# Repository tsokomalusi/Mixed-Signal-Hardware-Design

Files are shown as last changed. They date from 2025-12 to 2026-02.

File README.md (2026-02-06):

# Mixed-Signal-Hardware-Design

## 📌 Project Summary
This repository contains a mixed-signal hardware design project covering system-level design, schematic capture, analog simulation, and PCB layout.  
The project demonstrates best practices in analog/digital partitioning, component selection, simulation-driven design, and manufacturable PCB layout.

------------------------------------------------------------------------------------------------------------------------------------------------------------------------------------------
## 🧰 Tools Used
- **KiCad** – Schematic capture and PCB design  
- **LTSpice** – Analog circuit simulation  
- **STM32CubeIDE** – MCU pinout planning  
- **draw.io** – System block diagram
- **git and github** - version control system
-----------------------------------------------------------------------------------------------------------------------------------------------------------------------------------------
## 🧱 System Block Diagram

block_diagram

Refined version
  
block_diagram_refined

-----------------------------------------------------------------------------------------------------------------------------------------------------------------------------------------
## 🧩 Pinout Planning

mixed-signal-pinout_planning
-----------------------------------------------------------------------------------------------------------------------------------------------------------------------------------------
## 📐 Schematic Design

Root Sheet
root

Power circuitry
power

MCU circuitry
mcu

ADC circuirty
adc

DAC circuitry
dac

Key design considerations:
- Proper decoupling and grounding
- Separation of analog and digital domains
- Power integrity and signal integrity

------------------------------------------------------------------------------------------------------------------------------------------------------------------------------------------
## 🧩 PCB Layout

### PCB STACKUP 
- TOP LAYER :     SIG/POWER
- IN1 LAYER:      GND
- IN2 LAYER:      GND
- BOTTOM LAYER:   SIG/POWER

###  PCB All Layers
PCB_LAYOUT

### Top Layer
PCB_TOP

### Bottom Layer
PCB_BOTTOM

### 3D View
mixed_signal_hw_pcb_3D

PCB design highlights:
- Footprint creation
- Controlled impedance traces
- Avoiding: crosstalk, coupling, ground loops, inductance and radiation
- Via stitching, power puddles, keeping proper spacing between analog and digital circuits

-------------------------------------------------------------------------------------------------------------------------------------------------------------------------------------------
## 🔬 LTSpice Simulation

### AC Analysis Schematic
ac_analysis

### AC Analysis Response
ac_analysis_response

### DC Operating Point Analysis
dc_operating_point_analysis

DC_Operating_Point_Analysis

------------------------------------------------------------------------------------------------------------------------------------------------------------------------------------------
## 📜 License
This project is released for educational and portfolio purposes.

------------------------------------------------------------------------------------------------------------------------------------------------------------------------------------------
## 🙏 Acknowledgements

This project was developed as part of hands-on learning inspired by the course:

**“Mixed-Signal Hardware Design with KiCad”**  
Instructor: **Philip Salmony**  
Platform: **FEDEVEL Academy**  
Website: https://www.fedevel.com

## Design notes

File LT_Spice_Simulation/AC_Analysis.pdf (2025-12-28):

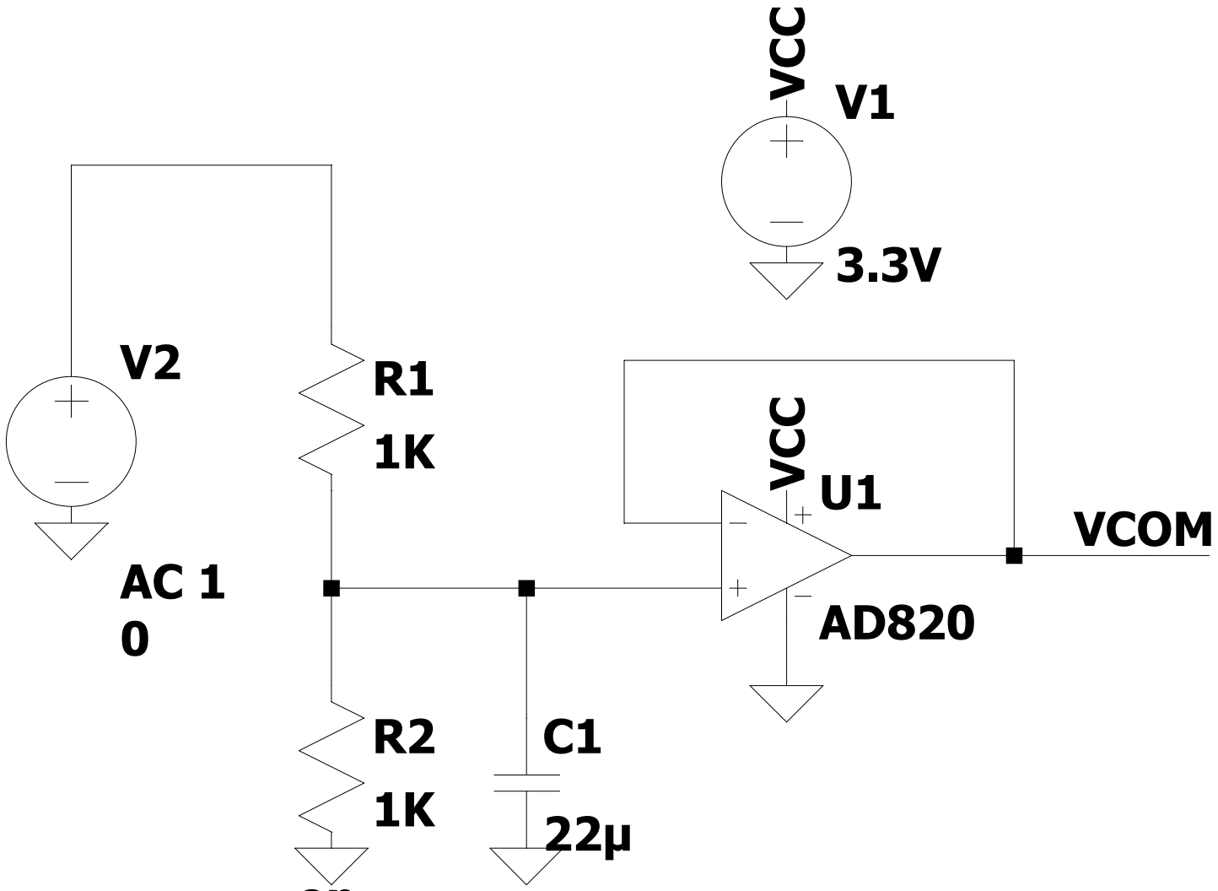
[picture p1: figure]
VCC VCC; VCOM

# .ac dec 100 1 25000

.op

--- C:\Users\Asus\OneDrive\Documents\LTspice\Draft1.asc ---

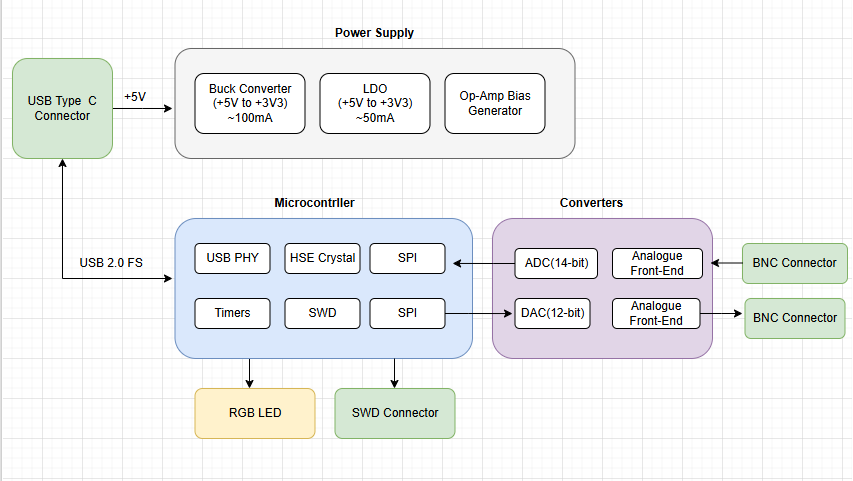
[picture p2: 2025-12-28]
Images/block_diagram_refined.png

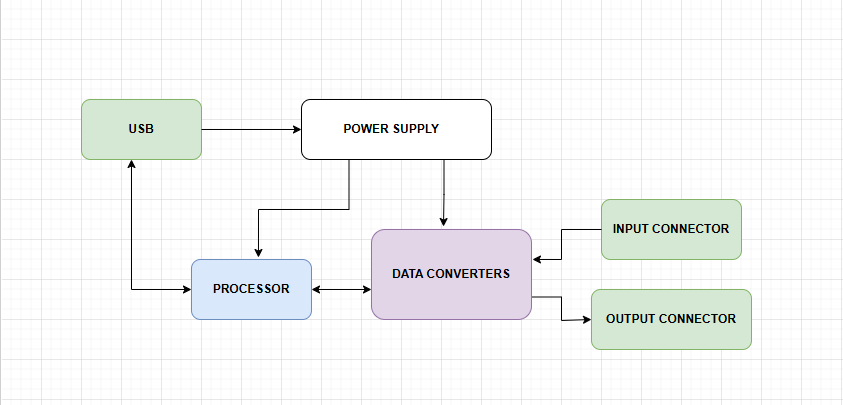
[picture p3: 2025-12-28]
Images/block_diagram.png

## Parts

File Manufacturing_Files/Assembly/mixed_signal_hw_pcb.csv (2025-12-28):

Reference | Qty | Value | Exclude from BOM | Exclude from Board | Footprint | Datasheet | Manufacturer | Manufacturer Part Number
Y200 | 1 | 16MHz |  |  | Crystal:Crystal_SMD_3225-4Pin_3.2x2.5mm | ~ | Epson | FA-238 16.000 MHz
U401 | 1 | MCP6001-OT |  |  | Package_TO_SOT_SMD:SOT-23-5 | https://ww1.microchip.com/downloads/en/DeviceDoc/MCP6001-1R-1U-2-4-1-MHz-Low-Power-Op-Amp-DS20001733L.pdf | Microchip Technology | MCP6001T‑I/OT
U400 | 1 | DAC7563SDGSR |  |  | DAC7563SDGSR:SOIC-10 |  | Texas Instruments | DAC7563SDGSR
U305 | 1 | MCP6001-OT |  |  | Package_TO_SOT_SMD:SOT-23-5 | https://ww1.microchip.com/downloads/en/DeviceDoc/MCP6001-1R-1U-2-4-1-MHz-Low-Power-Op-Amp-DS20001733L.pdf | Microchip Technology | MCP6001-OT
U303 | 1 | ADC141S626CIMM_NOPB |  |  | DAC7563SDGSR:SOIC-10 |  | Texas Instruments | ADC141S626CIMM
U302 | 1 | REF3033AIDBZ |  |  | Package_TO_SOT_SMD:SOT-23 | http://www.ti.com/lit/ds/symlink/ref3033.pdf | Texas Instruments | REF3033AIDBZ
U301 | 1 | MCP6001-OT |  |  | Package_TO_SOT_SMD:SOT-23-5 | https://ww1.microchip.com/downloads/en/DeviceDoc/MCP6001-1R-1U-2-4-1-MHz-Low-Power-Op-Amp-DS20001733L.pdf | Microchip Technology | MCP6001-OT
U300 | 1 | MCP6001-OT |  |  | Package_TO_SOT_SMD:SOT-23-5 | https://ww1.microchip.com/downloads/en/DeviceDoc/MCP6001-1R-1U-2-4-1-MHz-Low-Power-Op-Amp-DS20001733L.pdf | Microchip Technology | MCP6001-OT
U201 | 1 | USBLC6-2SC6 |  |  | Package_TO_SOT_SMD:SOT-23-6 | https://www.st.com/resource/en/datasheet/usblc6-2.pdf | ON Semiconductor | USBLC6-2SC6
U200 | 1 | STM32F103RCT6 |  |  | Package_QFP:LQFP-64_10x10mm_P0.5mm | https://www.st.com/resource/en/datasheet/stm32f103rc.pdf | STMicroelectronics | STM32F103RCT6
U101 | 1 | TLV62569DBV |  |  | Package_TO_SOT_SMD:SOT-23-5 | http://www.ti.com/lit/ds/symlink/tlv62568.pdf | Texas Instruments | TLV62569DBV
U100 | 1 | HT7533-1 |  |  | Package_TO_SOT_SMD:SOT-89-3 | https://www.holtek.com/documents/10179/116711/HT75xx-1v250.pdf | Holtek Semiconductor | HT7533-1
R405 | 1 | 49R9 |  |  | Resistor_SMD:R_0603_1608Metric | ~ | YAGEO | RC0603FR-0749R9L
R404 | 1 | 12K |  |  | Resistor_SMD:R_0603_1608Metric | ~ | YAGEO | RC0603FR-0712KL
R403 | 1 | 22K |  |  | Resistor_SMD:R_0603_1608Metric | ~ | YAGEO | RC0603FR-0722KL
R402 | 1 | 6K8 |  |  | Resistor_SMD:R_0603_1608Metric | ~ | YAGEO | RC0603FR-076K8L
R401 | 1 | 10K |  |  | Resistor_SMD:R_0603_1608Metric | ~ | YAGEO | RC0603FR-0710KL
R400 | 1 | 0R |  |  | Resistor_SMD:R_0603_1608Metric | ~ | YAGEO | RC0603JR-070RL
R309 | 1 | 0R |  |  | Resistor_SMD:R_0603_1608Metric | ~ | Yageo | RC0603JR-070RL
R308 | 1 | 49R9 |  |  | Resistor_SMD:R_0603_1608Metric | ~ | Yageo | RC0603FR-0749R9L
R307 | 1 | 1K |  |  | Resistor_SMD:R_0603_1608Metric | ~ | Yageo | RC0603FR-071KL
R306 | 1 | 1K |  |  | Resistor_SMD:R_0603_1608Metric | ~ | Yageo | RC0603FR-071KL
R305 | 1 | 12K |  |  | Resistor_SMD:R_0603_1608Metric | ~ | Yageo | RC0603FR-0712KL
R304 | 1 | 22K |  |  | Resistor_SMD:R_0603_1608Metric | ~ | Yageo | RC0603FR-0722KL
R303 | 1 | 6K8 |  |  | Resistor_SMD:R_0603_1608Metric | ~ | Yageo | RC0603FR-076K8L
R302 | 1 | 2M2 |  |  | Resistor_SMD:R_0805_2012Metric | ~ | Yageo | RC0805FR-072M2L
R301 | 1 | 2M2 |  |  | Resistor_SMD:R_0805_2012Metric | ~ | Yageo | RC0805FR-072M2L
R300 | 1 | 1K |  |  | Resistor_SMD:R_0603_1608Metric | ~ | Yageo | RC0603FR-071KL
R213 | 1 | 5K1 |  |  | Resistor_SMD:R_0603_1608Metric | ~ | Yageo | RC0603FR-075K1L
R212 | 1 | 5K1 |  |  | Resistor_SMD:R_0603_1608Metric | ~ | Yageo | RC0603FR-075K1L
R211 | 1 | 49R9 |  |  | Resistor_SMD:R_0603_1608Metric | ~ | Yageo | RC0603FR-0749R9L
R210 | 1 | 49R9 |  |  | Resistor_SMD:R_0603_1608Metric | ~ | Yageo | RC0603FR-0749R9L
R209 | 1 | 49R9 |  |  | Resistor_SMD:R_0603_1608Metric | ~ | Yageo | RC0603FR-0749R9L
R208 | 1 | 49R9 |  |  | Resistor_SMD:R_0603_1608Metric | ~ | Yageo | RC0603FR-0749R9L
R207 | 1 | 1K |  |  | Resistor_SMD:R_0603_1608Metric | ~ | Yageo | RC0603FR-071KL
R206 | 1 | 1K |  |  | Resistor_SMD:R_0603_1608Metric | ~ | Yageo | RC0603FR-071KL
R205 | 1 | 1K |  |  | Resistor_SMD:R_0603_1608Metric | ~ | Yageo | RC0603FR-071KL
R204 | 1 | 10K |  |  | Resistor_SMD:R_0603_1608Metric | ~ | Yageo | RC0603FR-0710KL
R203 | 1 | 1K5 |  |  | Resistor_SMD:R_0603_1608Metric | ~ | Yageo | RC0603FR-071K5L
R202 | 1 | 0R |  |  | Resistor_SMD:R_0603_1608Metric | ~ | Yageo | RC0603JR-070RL
R201 | 1 | 10K |  |  | Resistor_SMD:R_0603_1608Metric | ~ | Yageo | RC0603FR-0710KL
R200 | 1 | 10K |  |  | Resistor_SMD:R_0603_1608Metric | ~ | Yageo | RC0603FR-0710KL
R105 | 1 | 1K |  |  | Resistor_SMD:R_0603_1608Metric | ~ | YAGEO | RC0603FR-071KL
R104 | 1 | 1K |  |  | Resistor_SMD:R_0603_1608Metric | ~ | YAGEO | RC0603FR-071KL
R103 | 1 | 1K |  |  | Resistor_SMD:R_0603_1608Metric | ~ | YAGEO | RC0603FR-071KL
R102 | 1 | 22K |  |  | Resistor_SMD:R_0603_1608Metric | ~ | YAGEO | RC0603FR-0722KL
R101 | 1 | 100K |  |  | Resistor_SMD:R_0603_1608Metric | ~ | YAGEO | RC0603FR-07100KL
R100 | 1 | 10R |  |  | Resistor_SMD:R_0603_1608Metric | ~ | YAGEO | RC0603FR-0710RL
L200 | 1 | 10n |  |  | Inductor_SMD:L_0603_1608Metric | ~ | Murata | LQW18AN10NJ00D
L101 | 1 | 68u |  |  | Inductor_SMD:L_Sunlord_MWSA0603S | ~ | Sunlord | MWSA0603S-680K
L100 | 1 | 10n |  |  | Inductor_SMD:L_0603_1608Metric | ~ | Sunlord | MWSA0603S-100J
J400 | 1 | DOSIN-801-0031 |  |  | Connector_DIN:BNC | ~ | dosinconn | DOSIN-801-003
J300 | 1 | DOSIN-801-0031 |  |  | Connector_DIN:BNC | ~ | dosinconn | DOSIN-801-003
J201 | 1 | 2X5X1.27mm |  |  | Connector_PinHeader_1.27mm:PinHeader_2x05_P1.27mm_Vertical_SMD | ~ | Samtec | FTSH-105-01-L-DV-K
J200 | 1 | USB_C_Receptacle_USB2.0_16P |  |  | Connector_USB:USB_C_Receptacle_HRO_TYPE-C-31-M-12 | https://www.usb.org/sites/default/files/documents/usb_type-c.zip | Korean Hroparts Elec | TYPE-C-31-M-12
H4 | 1 | MountingHole_Pad | Excluded from BOM |  | MountingHole:MountingHole_3.2mm_M3_Pad_Via | ~
H3 | 1 | MountingHole_Pad | Excluded from BOM |  | MountingHole:MountingHole_3.2mm_M3_Pad_Via | ~
H2 | 1 | MountingHole_Pad | Excluded from BOM |  | MountingHole:MountingHole_3.2mm_M3_Pad_Via | ~
H1 | 1 | MountingHole_Pad | Excluded from BOM |  | MountingHole:MountingHole_3.2mm_M3_Pad_Via | ~
FL200 | 1 | DLW21SN900SQ2L |  |  | Inductor_SMD:choke | https://productfinder.pulseelectronics.com/api/open/product-attachments/datasheet/ph9455.105nl | Murata Electronics | DLW21SN900SQ2L
D400 | 1 | PESD3V3L1BA.115 |  |  | Diode_SMD:D_SOD-323 | https://www.littelfuse.com/~/media/electronics/datasheets/tvs_diode_arrays/littelfuse_tvs_diode_array_sd_c_datasheet.pdf.pdf | Nexperia | PESD3V3L1BA,115
D300 | 1 | PESD3V3L1BA.115 |  |  | Diode_SMD:D_SOD-323 | https://www.littelfuse.com/~/media/electronics/datasheets/tvs_diode_arrays/littelfuse_tvs_diode_array_sd_c_datasheet.pdf.pdf | Nexperia | PESD3V3L1BA,115
D205 | 1 | SD05_SOD323 |  |  | Diode_SMD:D_SOD-323 | https://www.littelfuse.com/~/media/electronics/datasheets/tvs_diode_arrays/littelfuse_tvs_diode_array_sd_c_datasheet.pdf.pdf | Nexperia | PESD3V3L1BA,115
D204 | 1 | SD05_SOD323 |  |  | Diode_SMD:D_SOD-323 | https://www.littelfuse.com/~/media/electronics/datasheets/tvs_diode_arrays/littelfuse_tvs_diode_array_sd_c_datasheet.pdf.pdf | Nexperia | PESD3V3L1BA,115
D203 | 1 | SD05_SOD323 |  |  | Diode_SMD:D_SOD-323 | https://www.littelfuse.com/~/media/electronics/datasheets/tvs_diode_arrays/littelfuse_tvs_diode_array_sd_c_datasheet.pdf.pdf | Nexperia | PESD3V3L1BA,115
D202 | 1 | PESD3V3L1BA,115 |  |  | Diode_SMD:D_SOD-323 | https://www.littelfuse.com/~/media/electronics/datasheets/tvs_diode_arrays/littelfuse_tvs_diode_array_sd_c_datasheet.pdf.pdf | Nexperia | PESD3V3L1BA,115
D201 | 1 | PESD3V3L1BA,115 |  |  | Diode_SMD:D_SOD-323 | https://www.littelfuse.com/~/media/electronics/datasheets/tvs_diode_arrays/littelfuse_tvs_diode_array_sd_c_datasheet.pdf.pdf | Nexperia | PESD3V3L1BA,115
D200 | 1 | LED_ARGB |  |  | LED_SMD:LED_AAA3528LSEEZGKQBKS_KNB | ~ | Kingbright | AAA3528LSEEZGKQBKS
D100 | 1 | GREEN |  |  | Diode_SMD:D_0805_2012Metric | ~ | LITEON | LTST-C170FKT
C406 | 1 | 100n |  |  | Capacitor_SMD:C_0603_1608Metric | ~ | YAGEO | CC0603ZRY5V7BB104
C405 | 1 | 1n |  |  | Capacitor_SMD:C_0603_1608Metric | ~ | Vishay / Vitramon | VJ0603H102KEBAO34
C404 | 1 | 150p |  |  | Capacitor_SMD:C_0603_1608Metric | ~ | Vishay / Vitramon | VJ0603A151JXAAC
C403 | 1 | 1n |  |  | Capacitor_SMD:C_0603_1608Metric | ~ | Vishay / Vitramon | VJ0603H102KEBAO34
C402 | 1 | 1u |  |  | Capacitor_SMD:C_0805_2012Metric | ~ | KYOCERA AVX | 08055D105KAT2A
C401 | 1 | 100n |  |  | Capacitor_SMD:C_0603_1608Metric | ~ | YAGEO | CC0603ZRY5V7BB104
C400 | 1 | 10u |  |  | Capacitor_SMD:C_0805_2012Metric | ~ | KYOCERA AVX | 0805X7R106KT1AT
C315 | 1 | 10u |  |  | Capacitor_SMD:C_0805_2012Metric | ~ | KYOCERA AVX | 0805X7R106KT1AT
C314 | 1 | 100n |  |  | Capacitor_SMD:C_0603_1608Metric | ~ | YAGEO | CC0603ZRY5V7BB104
C313 | 1 | 100n |  |  | Capacitor_SMD:C_0603_1608Metric | ~ | YAGEO | CC0603ZRY5V7BB104
C312 | 1 | 10u |  |  | Capacitor_SMD:C_0805_2012Metric | ~ | KYOCERA AVX | 0805X7R106KT1AT
C311 | 1 | 100n |  |  | Capacitor_SMD:C_0603_1608Metric | ~ | YAGEO | CC0603ZRY5V7BB104
C310 | 1 | 10u |  |  | Capacitor_SMD:C_0805_2012Metric | ~ | KYOCERA AVX | 0805X7R106KT1AT
C309 | 1 | 10u |  | Excluded from board | Capacitor_SMD:C_0805_2012Metric | ~ | KYOCERA AVX | 0805X7R106KT1AT
C308 | 1 | 10u |  |  | Capacitor_SMD:C_0805_2012Metric | ~ | KYOCERA AVX | 0805X7R106KT1AT
C307 | 1 | 150p |  |  | Capacitor_SMD:C_0603_1608Metric | ~ | Vishay / Vitramon | VJ0603A151JXAAC
C306 | 1 | 100n |  |  | Capacitor_SMD:C_0603_1608Metric | ~ | YAGEO | CC0603ZRY5V7BB104
C305 | 1 | 150p |  |  | Capacitor_SMD:C_0603_1608Metric | ~ | Vishay / Vitramon | VJ0603A151JXAAC
C304 | 1 | 1n |  |  | Capacitor_SMD:C_0603_1608Metric | ~ | Vishay / Vitramon | VJ0603H102KEBAO34
C303 | 1 | 1n |  |  | Capacitor_SMD:C_0603_1608Metric | ~ | Vishay / Vitramon | VJ0603H102KEBAO34
C302 | 1 | 100n |  |  | Capacitor_SMD:C_0603_1608Metric | ~ | YAGEO | CC0603ZRY5V7BB104
C301 | 1 | 100n |  |  | Capacitor_SMD:C_0603_1608Metric | ~ | YAGEO | CC0603ZRY5V7BB104
C300 | 1 | 150p |  |  | Capacitor_SMD:C_0603_1608Metric | ~ | Vishay / Vitramon | VJ0603A151JXAAC
C213 | 1 | 100n |  |  | Capacitor_SMD:C_0603_1608Metric | ~ | YAGEO | CC0603ZRY5V7BB104
C212 | 1 | 100n |  |  | Capacitor_SMD:C_0603_1608Metric | ~ | YAGEO | CC0603ZRY5V7BB104
C211 | 1 | 100n |  |  | Capacitor_SMD:C_0603_1608Metric | ~ | YAGEO | CC0603ZRY5V7BB104
C210 | 1 | 10p |  |  | Capacitor_SMD:C_0603_1608Metric | ~ | Vishay / Vitramon | VJ0603A100FXBAC
C209 | 1 | 10p |  |  | Capacitor_SMD:C_0603_1608Metric | ~ | Vishay / Vitramon | VJ0603A100FXBAC
C208 | 1 | 1u |  |  | Capacitor_SMD:C_0805_2012Metric | ~ | KYOCERA AVX | 08055D105KAT2A
C207 | 1 | 1u |  |  | Capacitor_SMD:C_0805_2012Metric | ~ | KYOCERA AVX | 08055D105KAT2A
C206 | 1 | 10n |  |  | Capacitor_SMD:C_0603_1608Metric | ~ | Vishay / Vitramon | VJ0603Y103KXJAC31X
C205 | 1 | 100n |  |  | Capacitor_SMD:C_0603_1608Metric | ~ | YAGEO | CC0603ZRY5V7BB104
C204 | 1 | 100n |  |  | Capacitor_SMD:C_0603_1608Metric | ~ | YAGEO | CC0603ZRY5V7BB104
C203 | 1 | 100n |  |  | Capacitor_SMD:C_0603_1608Metric | ~ | YAGEO | CC0603ZRY5V7BB104
C202 | 1 | 100n |  |  | Capacitor_SMD:C_0603_1608Metric | ~ | YAGEO | CC0603ZRY5V7BB104
C201 | 1 | 100n |  |  | Capacitor_SMD:C_0603_1608Metric | ~ | YAGEO | CC0603ZRY5V7BB104
C200 | 1 | 10u |  |  | Capacitor_SMD:C_0805_2012Metric | ~ | KYOCERA AVX | 0805X7R106KT1AT
C108 | 1 | 100n |  |  | Capacitor_SMD:C_0603_1608Metric | ~ | YAGEO | CC0603ZRY5V7BB104
C107 | 1 | 22u |  |  | Capacitor_SMD:C_0805_2012Metric | ~ | KYOCERA AVX | 0805YD226MAT2A
C106 | 1 | DNP |  |  | Capacitor_SMD:C_0805_2012Metric | ~
C105 | 1 | 22u |  |  | Capacitor_SMD:C_0805_2012Metric | ~ | KYOCERA AVX | 0805YD226MAT2A
C104 | 1 | 22u |  |  | Capacitor_SMD:C_0805_2012Metric | ~ | KYOCERA AVX | 0805YD226MAT2A
C103 | 1 | 22u |  |  | Capacitor_SMD:C_0805_2012Metric | ~ | KYOCERA AVX | 0805YD226MAT2A
C102 | 1 | 22u |  |  | Capacitor_SMD:C_0805_2012Metric | ~ | KYOCERA AVX | 0805YD226MAT2A
C101 | 1 | 1u |  |  | Capacitor_SMD:C_0805_2012Metric | ~ | KYOCERA AVX | 08055D105KAT2A
C100 | 1 | 1u |  |  | Capacitor_SMD:C_0805_2012Metric | ~ | KYOCERA AVX | 08055D105KAT2A

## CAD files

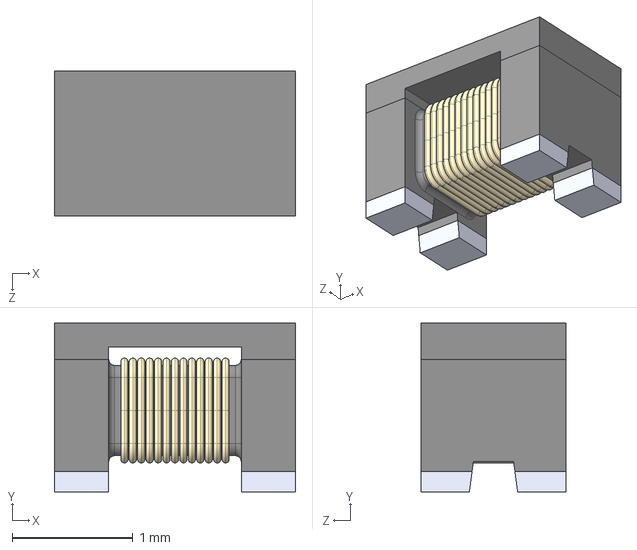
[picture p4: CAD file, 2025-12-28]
Step_Files/DLW21SN900SQ2L.step
2.00 x 1.40 x 1.20 mm

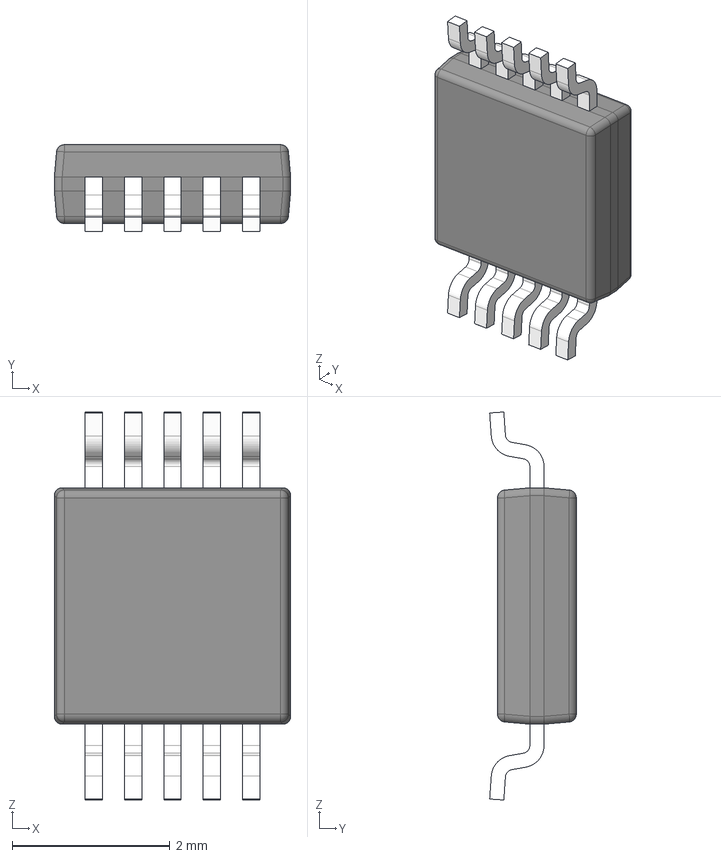
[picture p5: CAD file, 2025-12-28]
Step_Files/DGS0010A.stp
3.00 x 1.10 x 4.93 mm
BODY-SO
LEAD-SO x 10
PIN1-ID

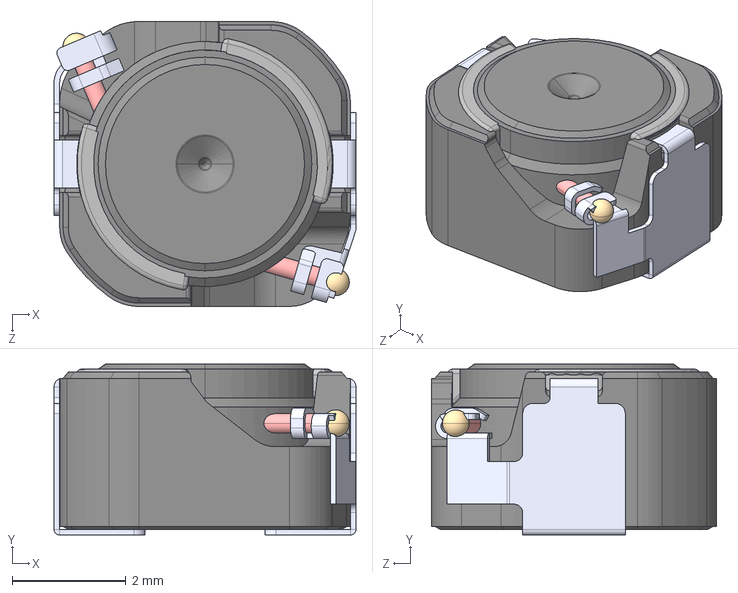
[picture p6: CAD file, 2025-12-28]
Step_Files/CLF5030NIT-680M-D.step
5.30 x 3.00 x 5.00 mm

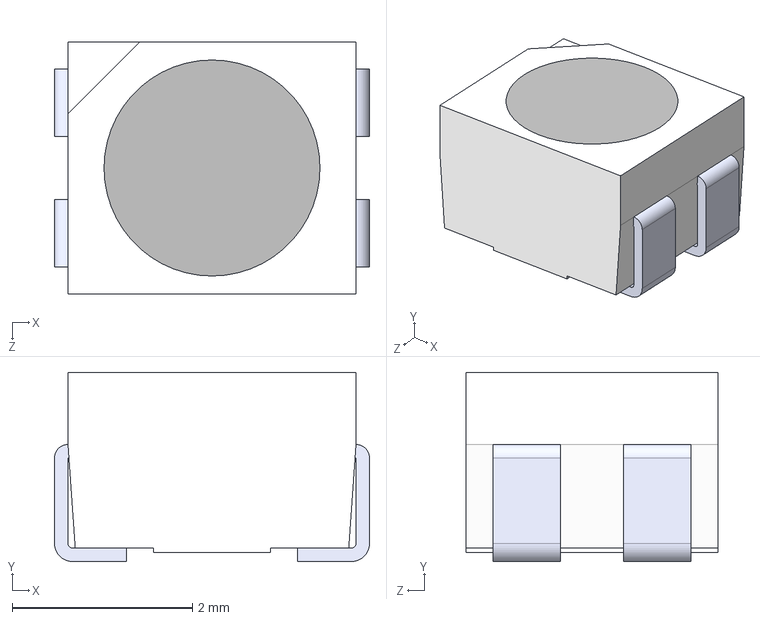
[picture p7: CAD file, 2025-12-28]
Step_Files/AAA3528LSEEZGKQBKS.step
3.50 x 2.10 x 2.80 mm

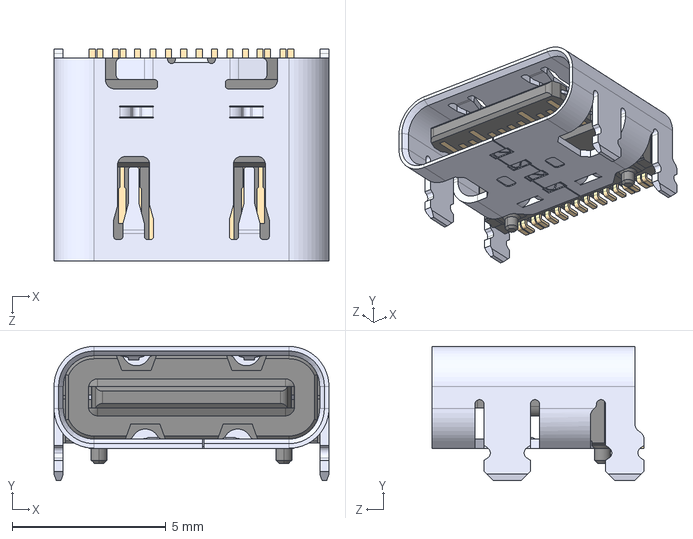
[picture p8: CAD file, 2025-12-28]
Step_Files/DX07S016JA1R1500.step
8.94 x 4.36 x 6.90 mm

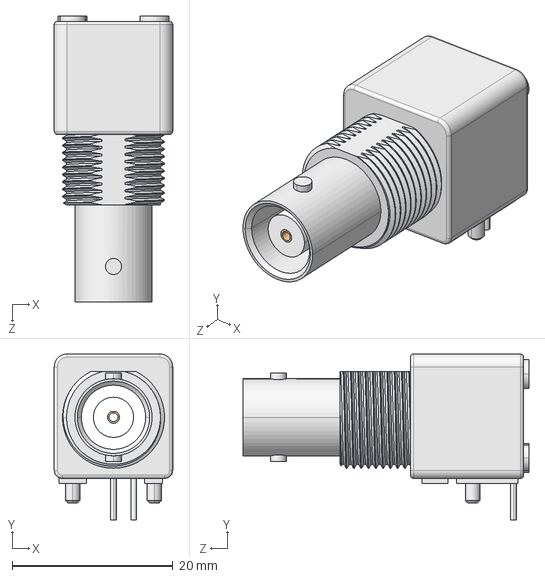
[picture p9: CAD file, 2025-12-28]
Step_Files/5222092-1.step
14.8 x 20.7 x 35.6 mm

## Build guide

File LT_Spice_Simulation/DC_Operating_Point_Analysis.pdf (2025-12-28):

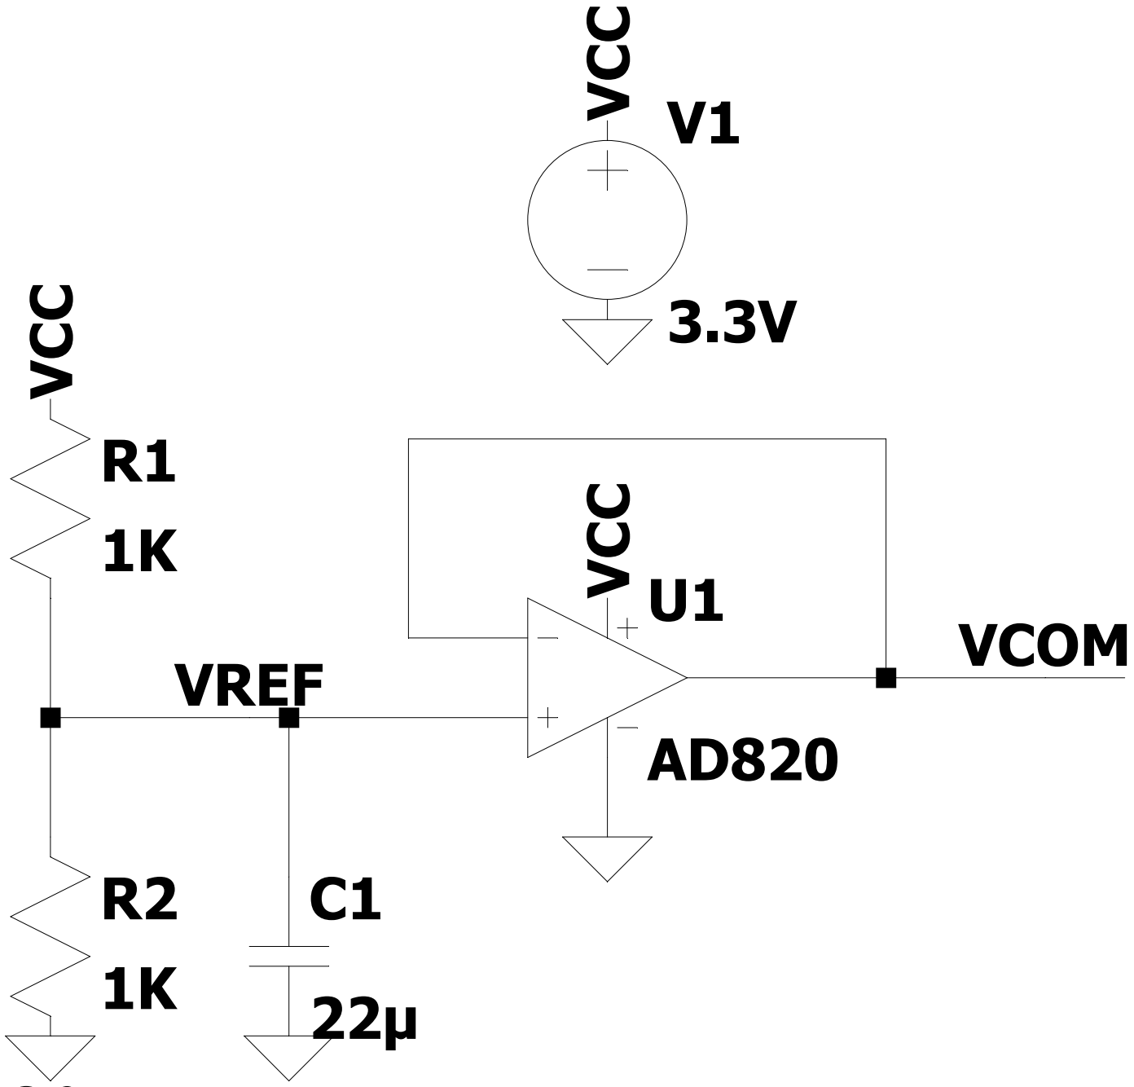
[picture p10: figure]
VCC VCC VCC; VCOM VREF

.op

--- C:\Users\Asus\OneDrive\Documents\LTspice\Draft1.asc ---

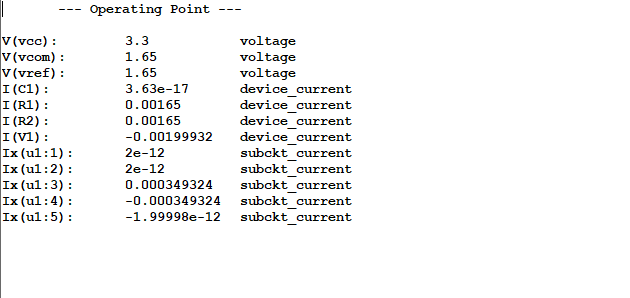
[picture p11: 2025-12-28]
LT_Spice_Simulation/DC_Operating_Point_Analysis.png

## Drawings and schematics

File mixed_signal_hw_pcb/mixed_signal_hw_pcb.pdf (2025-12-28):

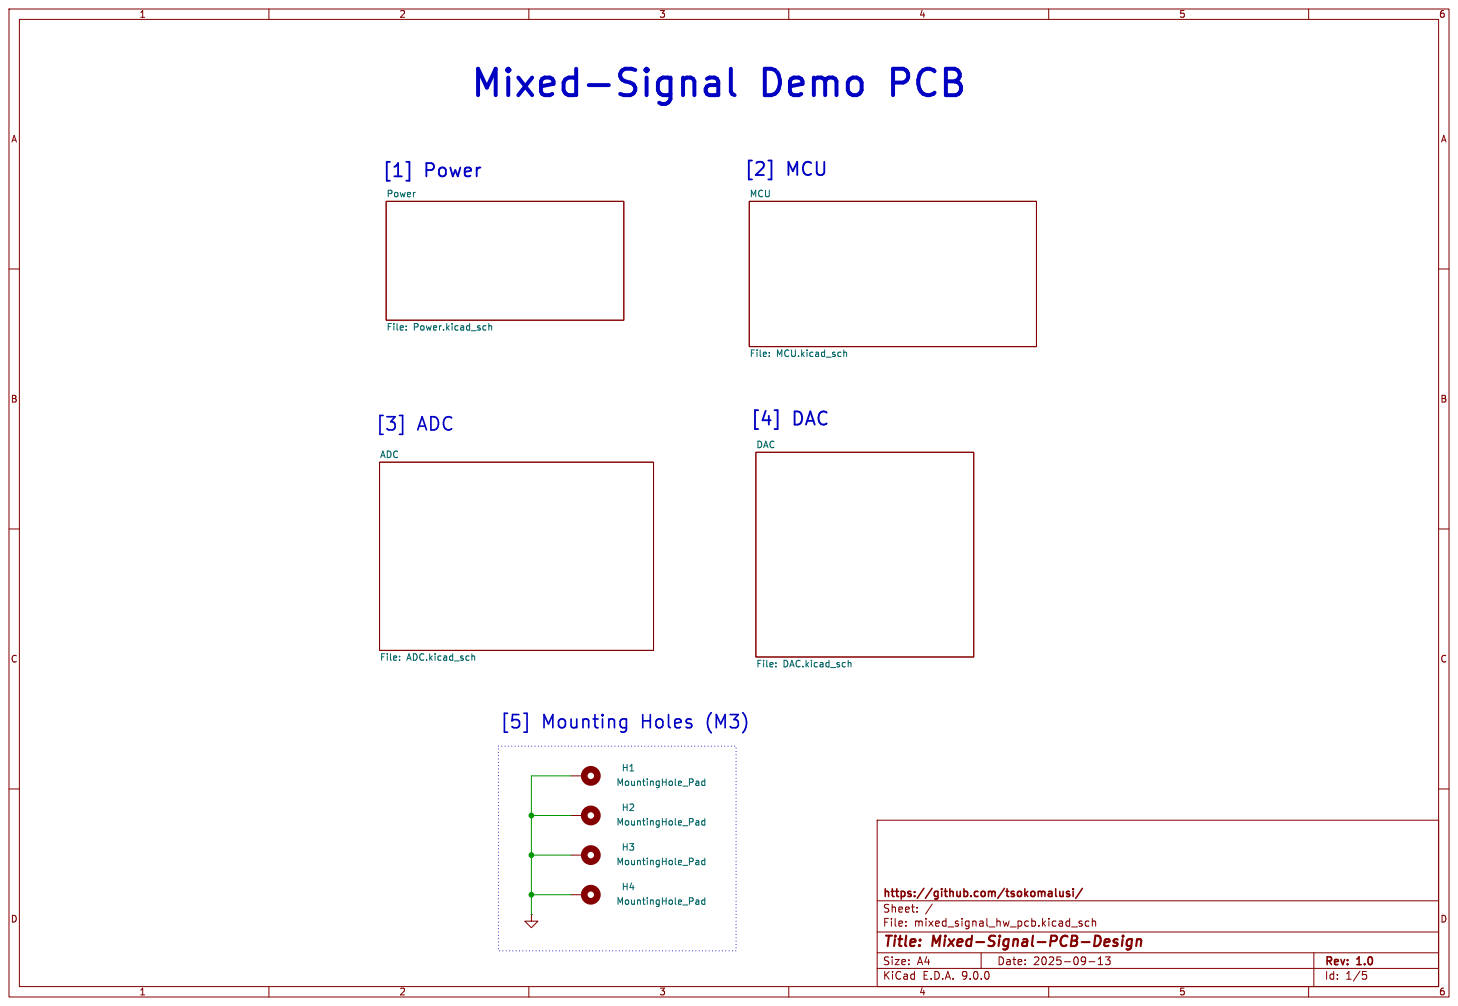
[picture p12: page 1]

File: mixed_signal_hw_pcb.kicad_sch Sheet: / https://github.com/tsokomalusi/ DAC

Id: 1/5 Title: Mixed-Signal-PCB-Design

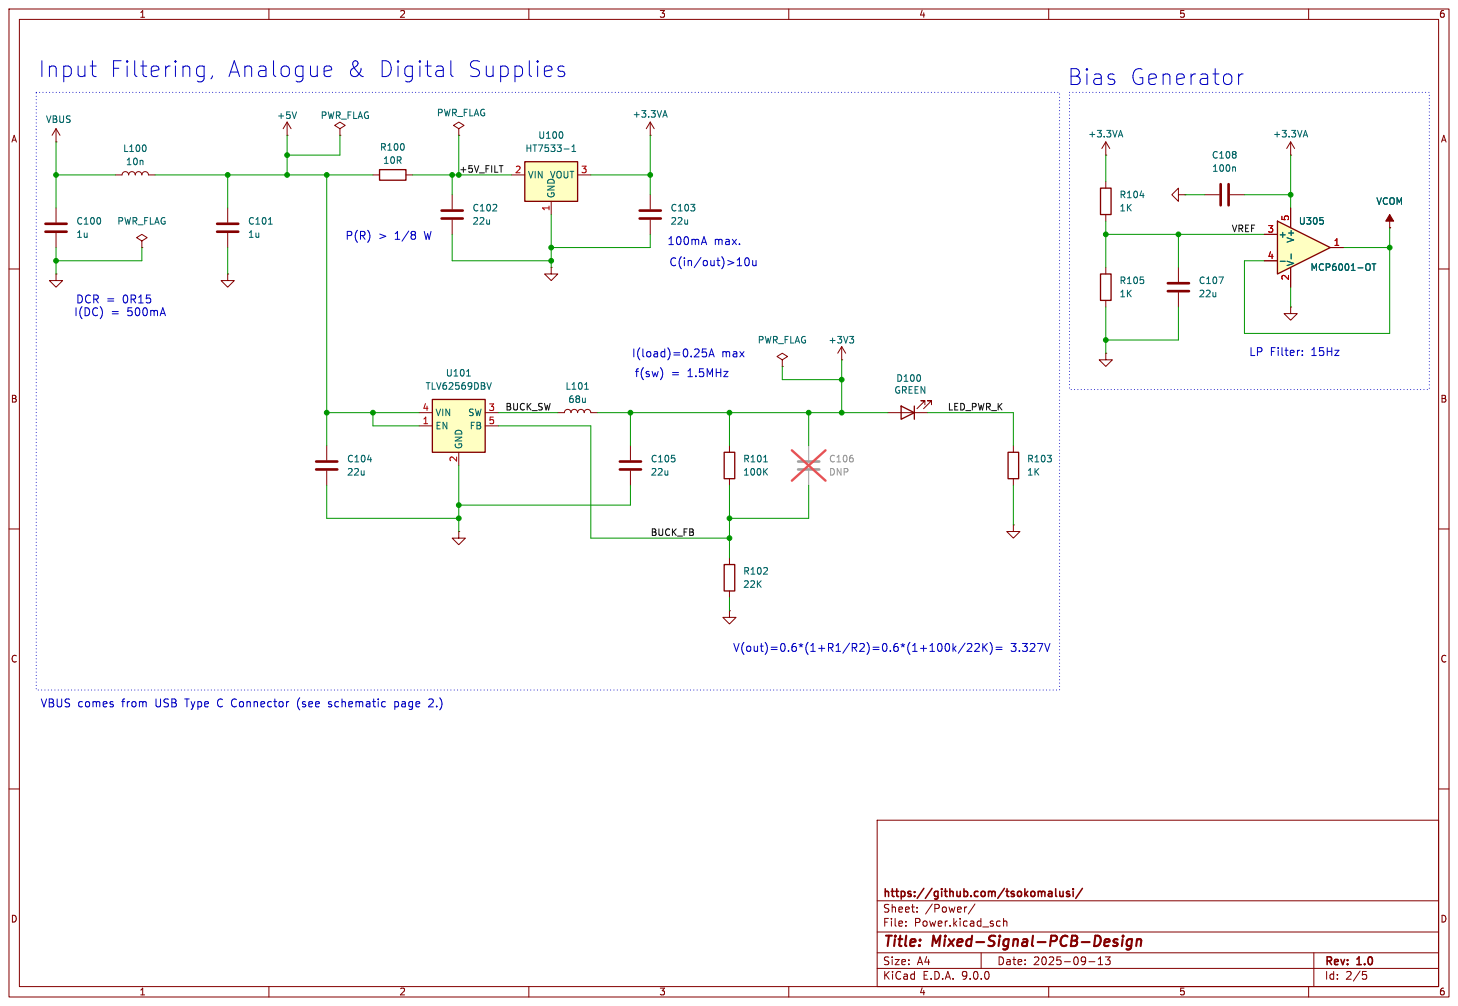
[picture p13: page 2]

File: Power.kicad_sch Sheet: /Power/ https://github.com/tsokomalusi/

Id: 2/5 Title: Mixed-Signal-PCB-Design

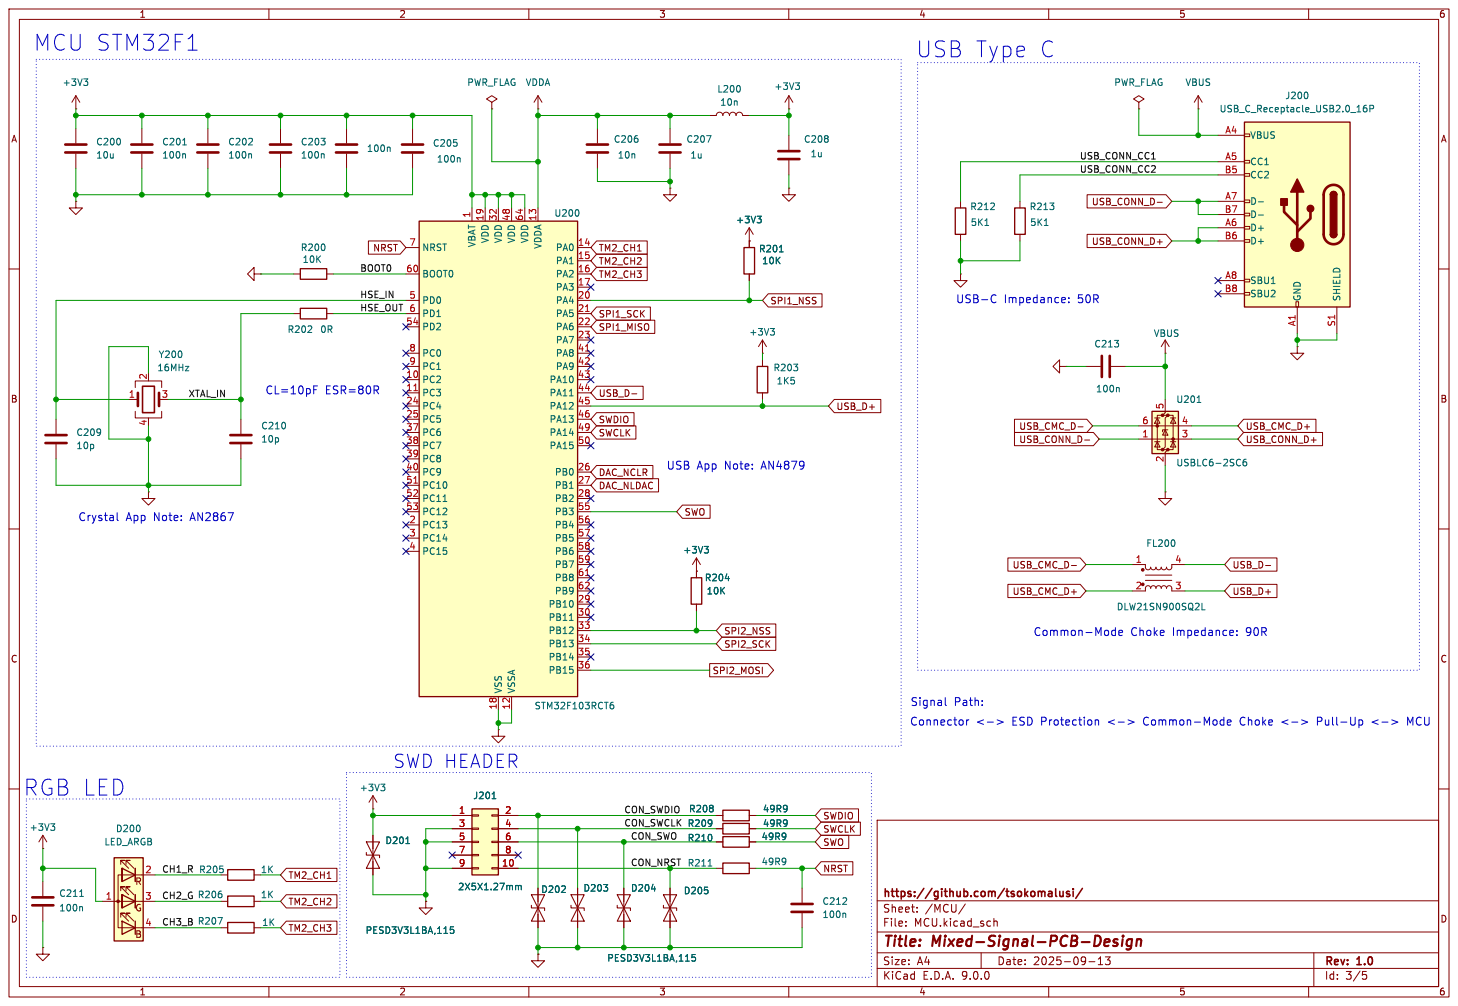
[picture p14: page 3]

1 VDD 19 VDD 32 VSS 18 VDD 48 VSSA 12 VDD 64 VDDA 13 PA0 14 PA1 15 PA2 16 PA3 17 PA4 20 PA5 21 PA6 22 PA7 23 PA8 41 PA9 42 PA10 43 PA11 44 PA12 45 PA13 46 PA14 49 PA15 50 PB0 26 PB1 27 PB2 28 PB3 55 PB4 56 PB5 57 PB6 58 PB7 59 PB8 61 PB9 62 PB10 29 PB11 30 PB12 33 PB13 34 PB14 35 PB15 36 U200 STM32F103RCT6DAC_NLDAC

Signal Path: USB App Note: AN4879 SWD HEADER

Id: 3/5 Title: Mixed-Signal-PCB-Design

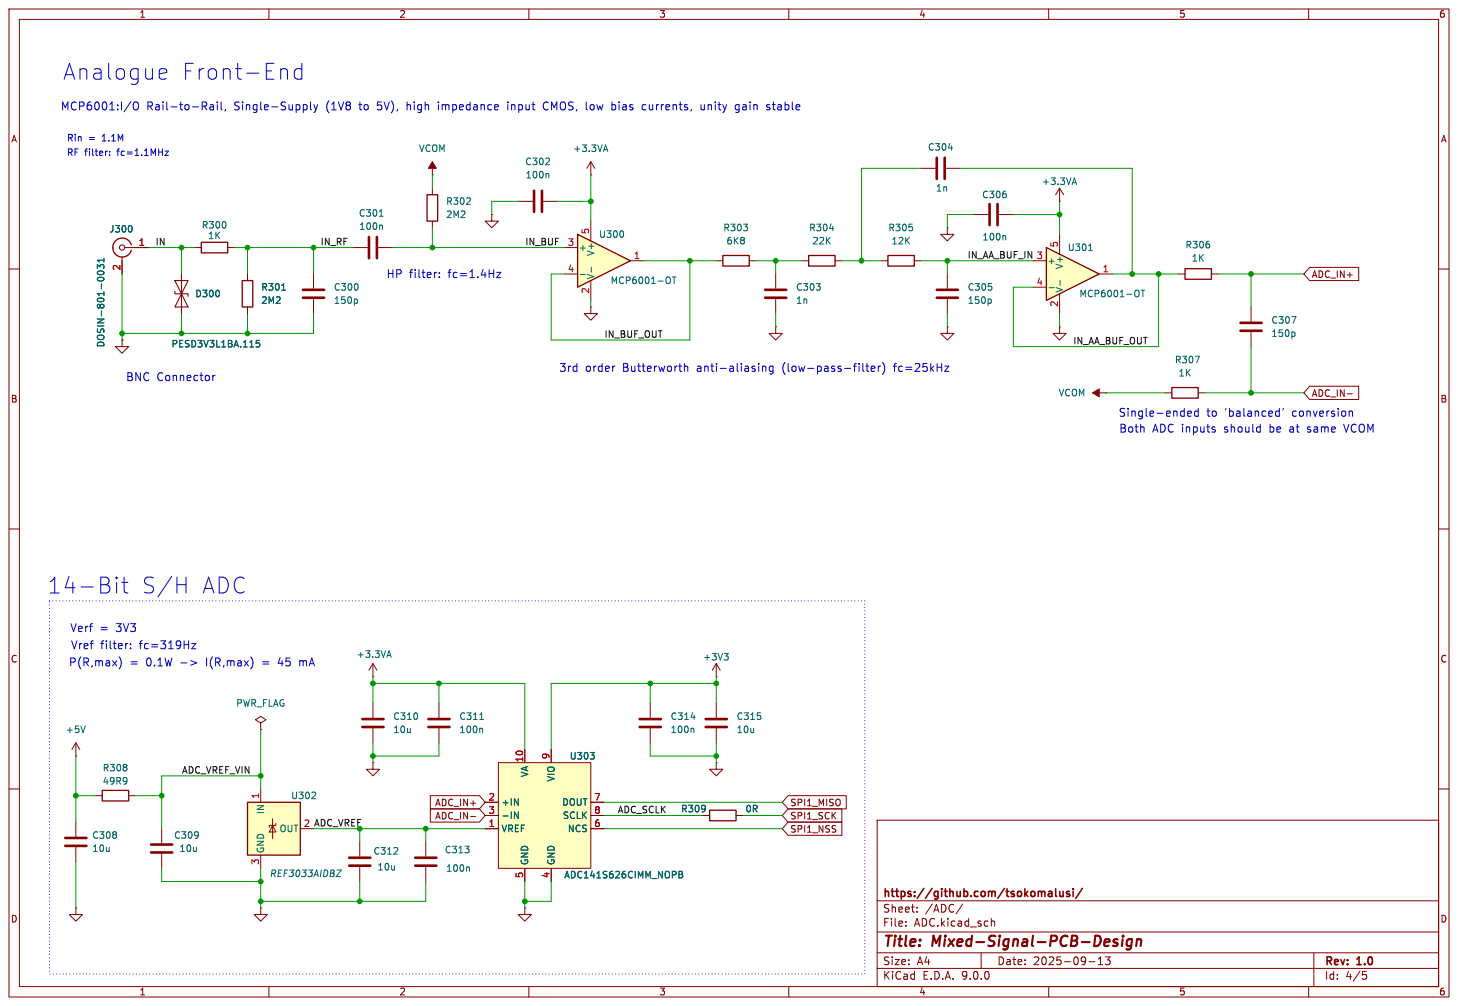
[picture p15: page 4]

Id: 4/5 Title: Mixed-Signal-PCB-Design

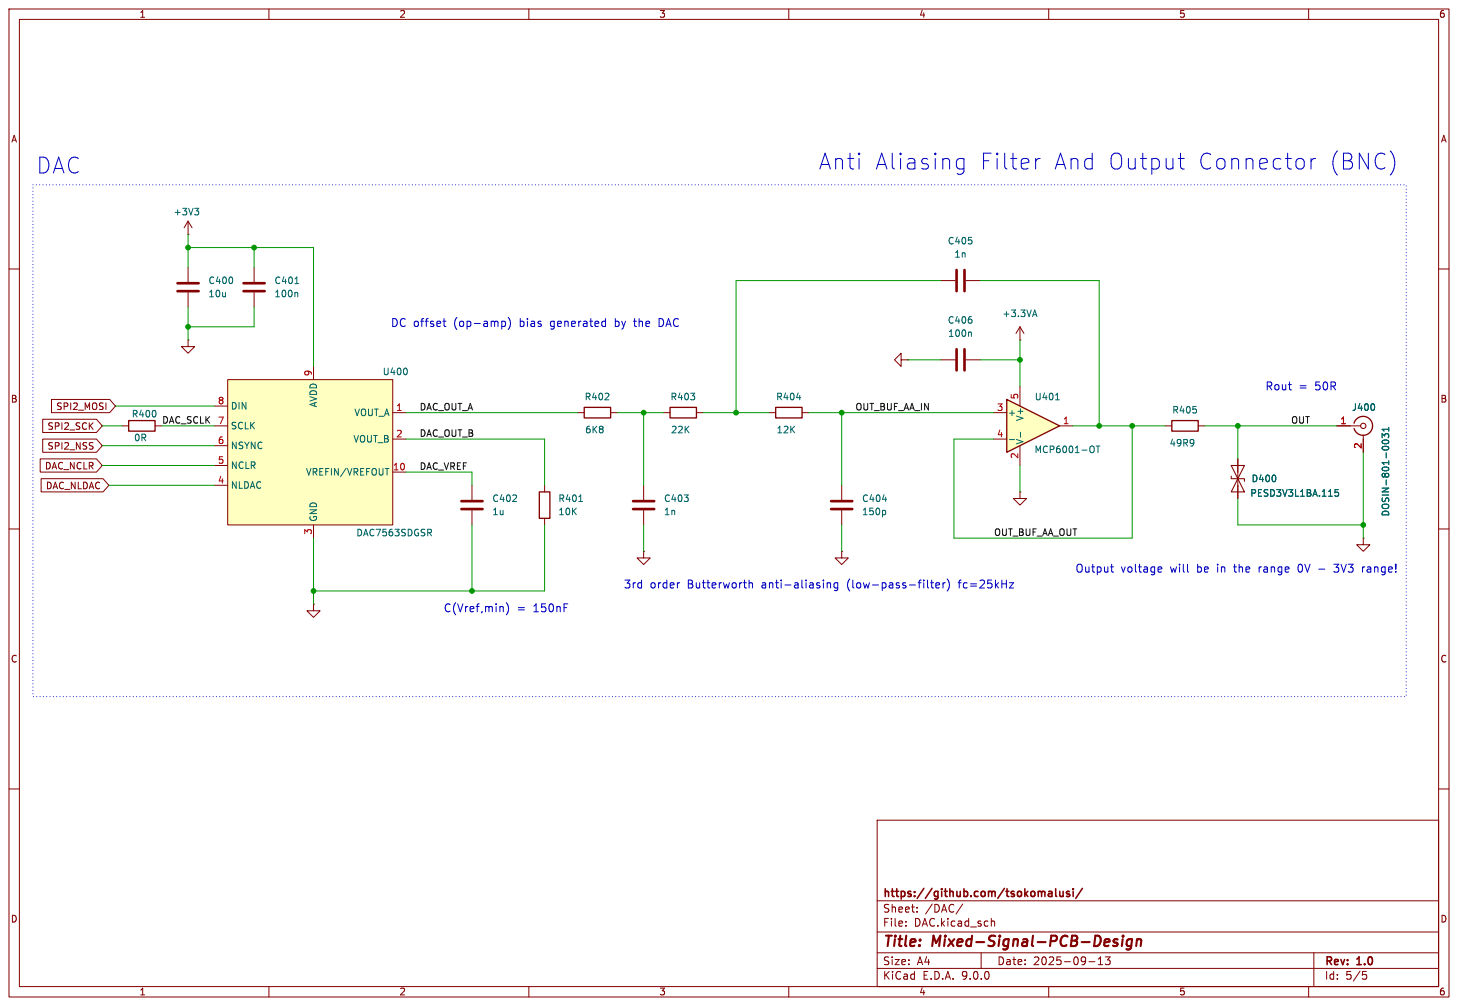
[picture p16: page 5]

Output voltage will be in the range 0V - 3V3 range! J400 DOSIN-801-0031

File: DAC.kicad_sch Sheet: /DAC/ https://github.com/tsokomalusi/

Id: 5/5 Title: Mixed-Signal-PCB-Design

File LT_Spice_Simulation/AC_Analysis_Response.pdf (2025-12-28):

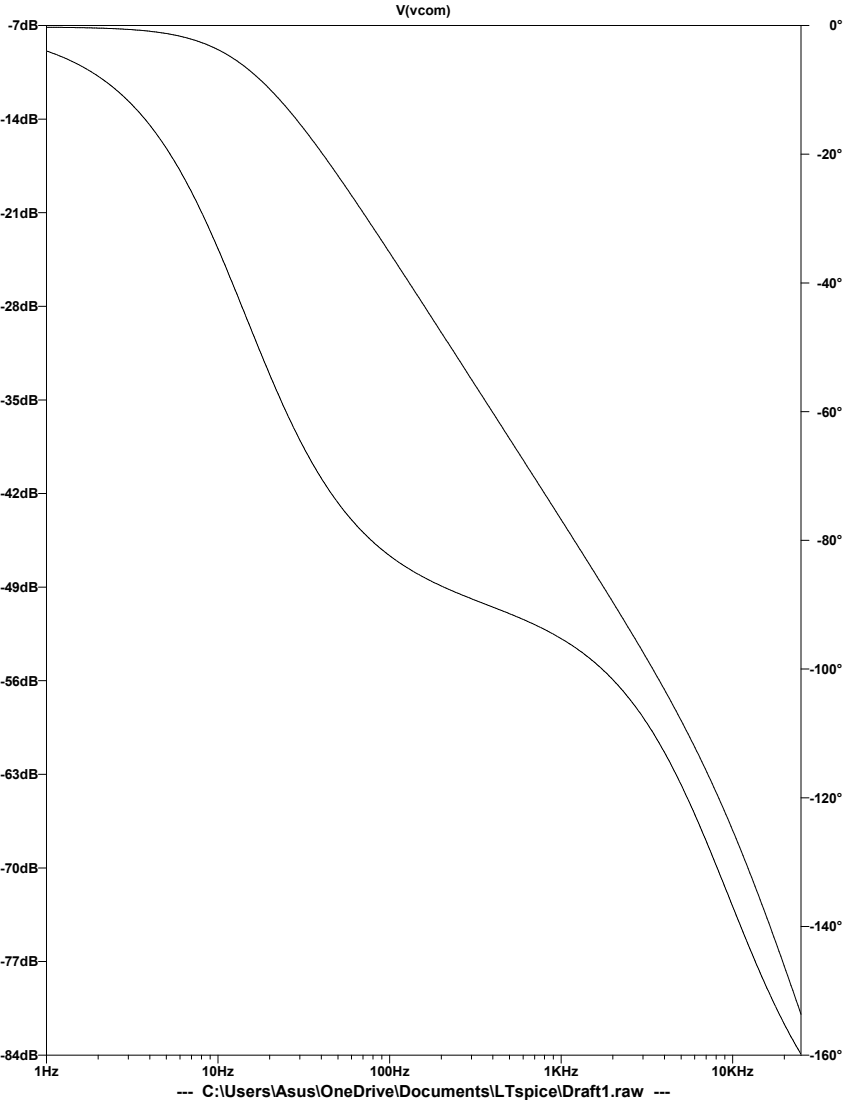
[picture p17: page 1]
1KHz; 10KHz; V(vcom)

--- C:\Users\Asus\OneDrive\Documents\LTspice\Draft1.raw ---

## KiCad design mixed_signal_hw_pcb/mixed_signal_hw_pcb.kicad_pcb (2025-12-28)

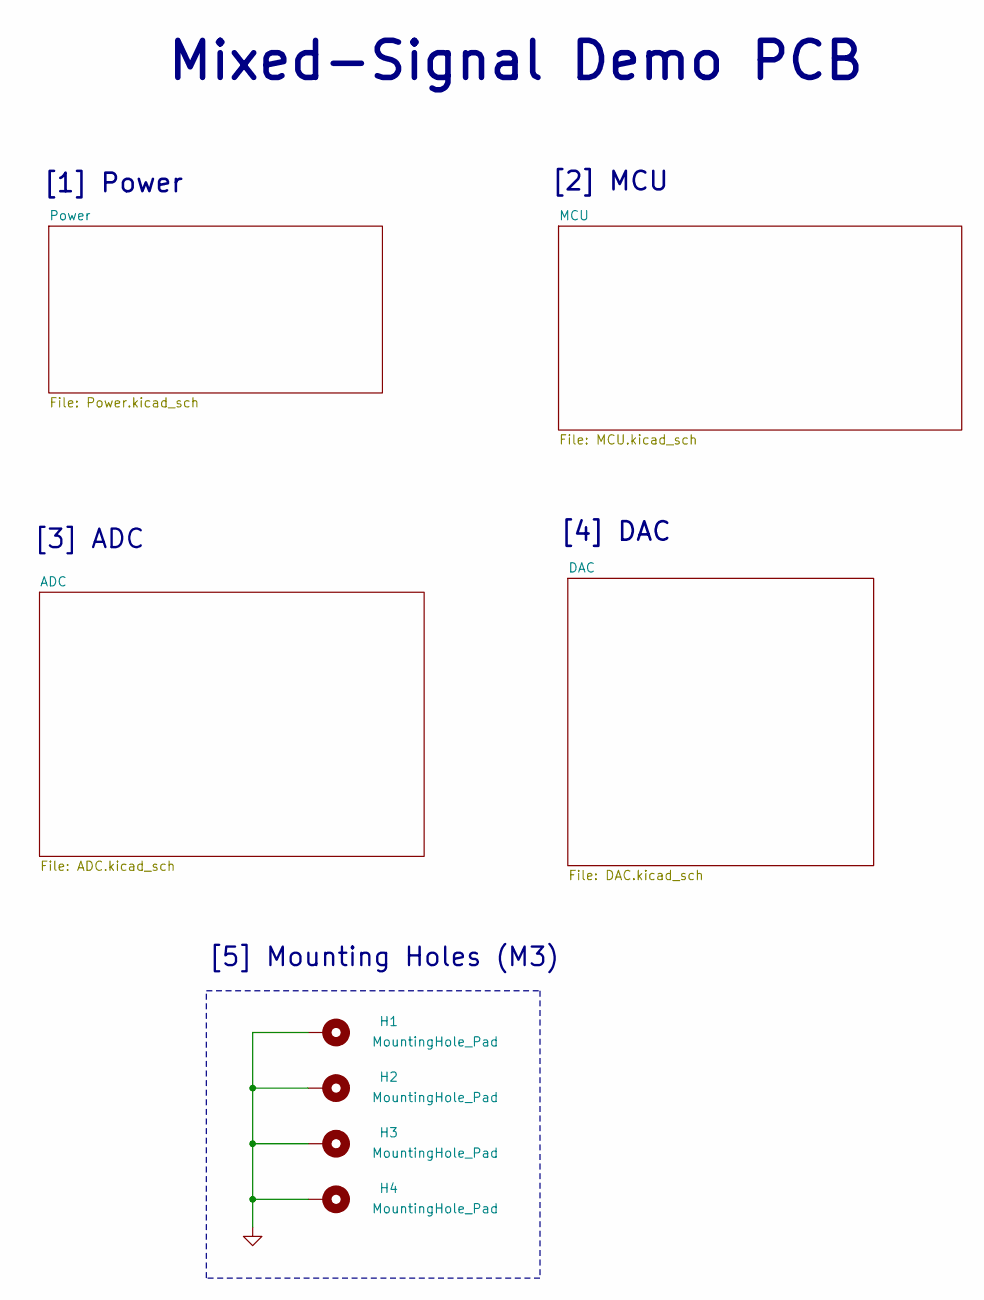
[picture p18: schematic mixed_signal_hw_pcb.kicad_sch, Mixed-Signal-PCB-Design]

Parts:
H1, H2, H3, H4: MountingHole_Pad; MountingHole_3.2mm_M3_Pad_Via

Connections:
GND: H1.1, H2.1, H3.1, H4.1; also elsewhere on the board

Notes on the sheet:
Mixed-Signal Demo PCB
[4] DAC
[5] Mounting Holes (M3)
[3] ADC
[2] MCU
[1] Power

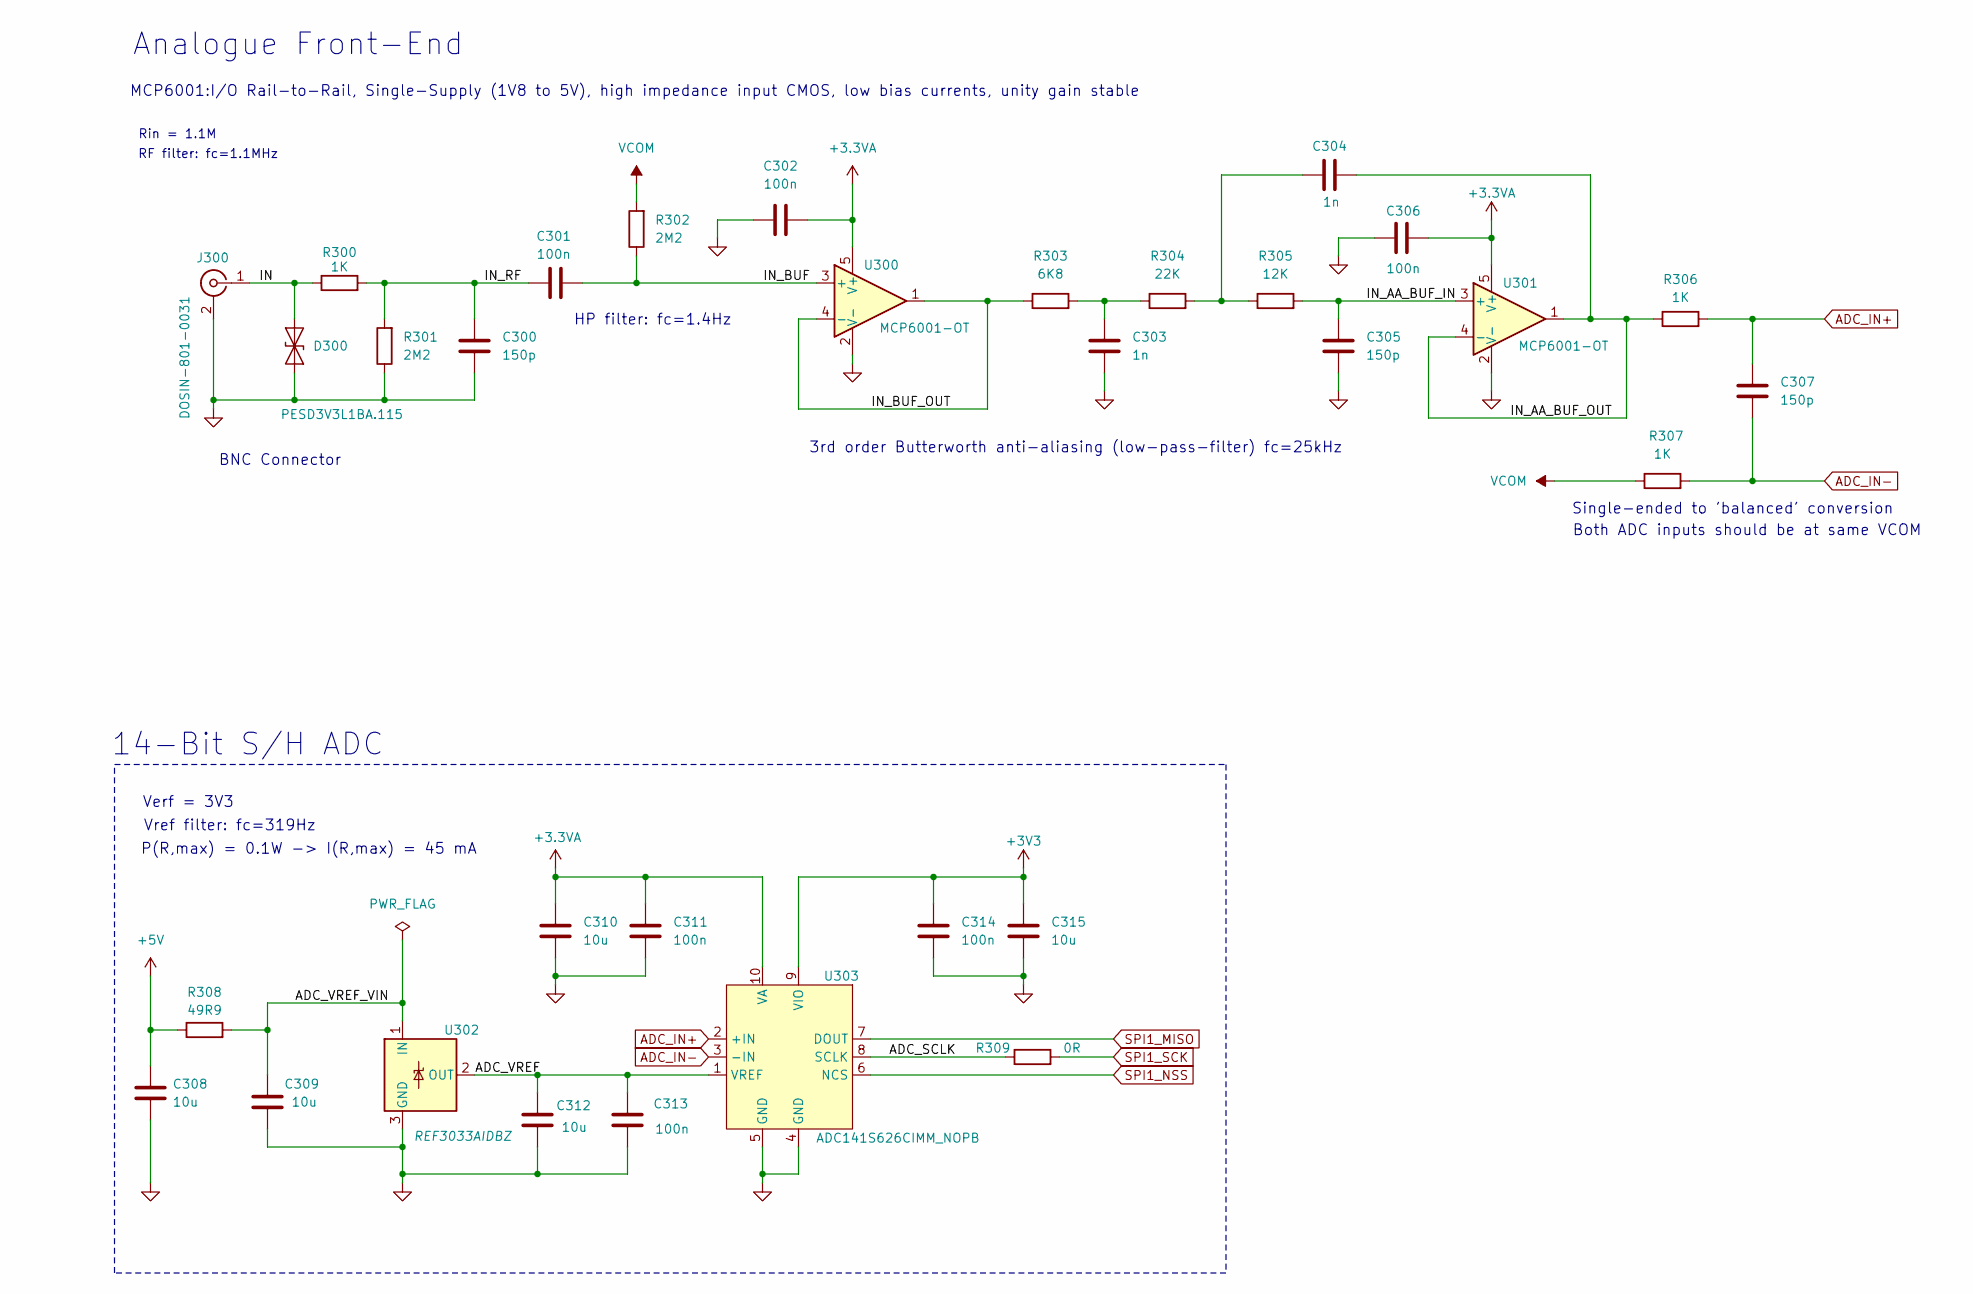
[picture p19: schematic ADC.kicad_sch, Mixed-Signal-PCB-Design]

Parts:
C300, C305, C307: 150p; C_0603_1608Metric; Manufacturer Part Number VJ0603A151JXAAC
C301, C302, C306, C311, C313, C314: 100n; C_0603_1608Metric; Manufacturer Part Number CC0603ZRY5V7BB104
C303, C304: 1n; C_0603_1608Metric; Manufacturer Part Number VJ0603H102KEBAO34
C308, C309, C310, C312, C315: 10u; C_0805_2012Metric; Manufacturer Part Number 0805X7R106KT1AT
D300: PESD3V3L1BA.115; D_SOD-323; Manufacturer Part Number PESD3V3L1BA,115
J300: DOSIN-801-0031; BNC; Manufacturer Part Number DOSIN-801-003
R300, R306, R307: 1K; R_0603_1608Metric; Manufacturer Part Number RC0603FR-071KL
R301, R302: 2M2; R_0805_2012Metric; Manufacturer Part Number RC0805FR-072M2L
R303: 6K8; R_0603_1608Metric; Manufacturer Part Number RC0603FR-076K8L
R304: 22K; R_0603_1608Metric; Manufacturer Part Number RC0603FR-0722KL
R305: 12K; R_0603_1608Metric; Manufacturer Part Number RC0603FR-0712KL
R308: 49R9; R_0603_1608Metric; Manufacturer Part Number RC0603FR-0749R9L
R309: 0R; R_0603_1608Metric; Manufacturer Part Number RC0603JR-070RL
U300, U301: MCP6001-OT; SOT-23-5; Manufacturer Part Number MCP6001-OT
U302: REF3033AIDBZ; SOT-23; Manufacturer Part Number REF3033AIDBZ
U303: ADC141S626CIMM_NOPB; SOIC-10; Manufacturer Part Number ADC141S626CIMM

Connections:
+3.3VA: C302.2, C306.2, C310.1, C311.1, U300.5 (V+), U301.5 (V+), U303.10 (VA); also elsewhere on the board
+3V3: C314.1, C315.1, U303.9 (VIO); also elsewhere on the board
+5V: C308.1, R308.1; also elsewhere on the board
/ADC/ADC_SCLK: R309.1, U303.8 (SCLK)
/ADC/ADC_VREF: C312.1, C313.1, U302.2 (OUT), U303.1 (VREF)
/ADC/ADC_VREF_VIN: C309.1, R308.2, U302.1 (IN)
/ADC/IN: D300.2 (A2), J300.1 (In), R300.1
/ADC/IN_AA_BUF_IN: C305.1, R305.2, U301.3 (+)
/ADC/IN_AA_BUF_OUT: C304.2, R306.1, U301.1, U301.4 (-)
/ADC/IN_BUF: C301.2, R302.1, U300.3 (+)
/ADC/IN_BUF_OUT: R303.1, U300.1, U300.4 (-)
/ADC/IN_RF: C300.1, C301.1, R300.2, R301.2
ADC_IN+: C307.1, R306.2, U303.2 (+IN)
ADC_IN-: C307.2, R307.2, U303.3 (-IN)
GND: C300.2, C302.1, C303.2, C305.2, C306.1, C308.2, C309.2, C310.2, C311.2, C312.2, C313.2, C314.2, C315.2, D300.1 (A1), J300.2 (Ext), R301.1, U300.2 (V-), U301.2 (V-), U302.3 (GND), U303.4 (GND), U303.5 (GND); also elsewhere on the board
unnamed: C303.1, R303.2, R304.1
unnamed: C304.1, R304.2, R305.1
SPI1_MISO: U303.7 (DOUT); also elsewhere on the board
SPI1_NSS: U303.6 (NCS); also elsewhere on the board
SPI1_SCK: R309.2; also elsewhere on the board
VCOM: R302.2, R307.1; also elsewhere on the board

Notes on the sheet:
Verf = 3V3
HP filter: fc=1.4Hz
BNC Connector
Rin = 1.1M
Vref filter: fc=319Hz
14-Bit S/H ADC
Single-ended to 'balanced' conversion
RF filter: fc=1.1MHz
P(R,max) = 0.1W -> I(R,max) = 45 mA
Analogue Front-End
3rd order Butterworth anti-aliasing (low-pass-filter) fc=25kHz
MCP6001:I/O Rail-to-Rail, Single-Supply (1V8 to 5V), high impedance input CMOS, low bias currents, unity gain stable
Both ADC inputs should be at same VCOM

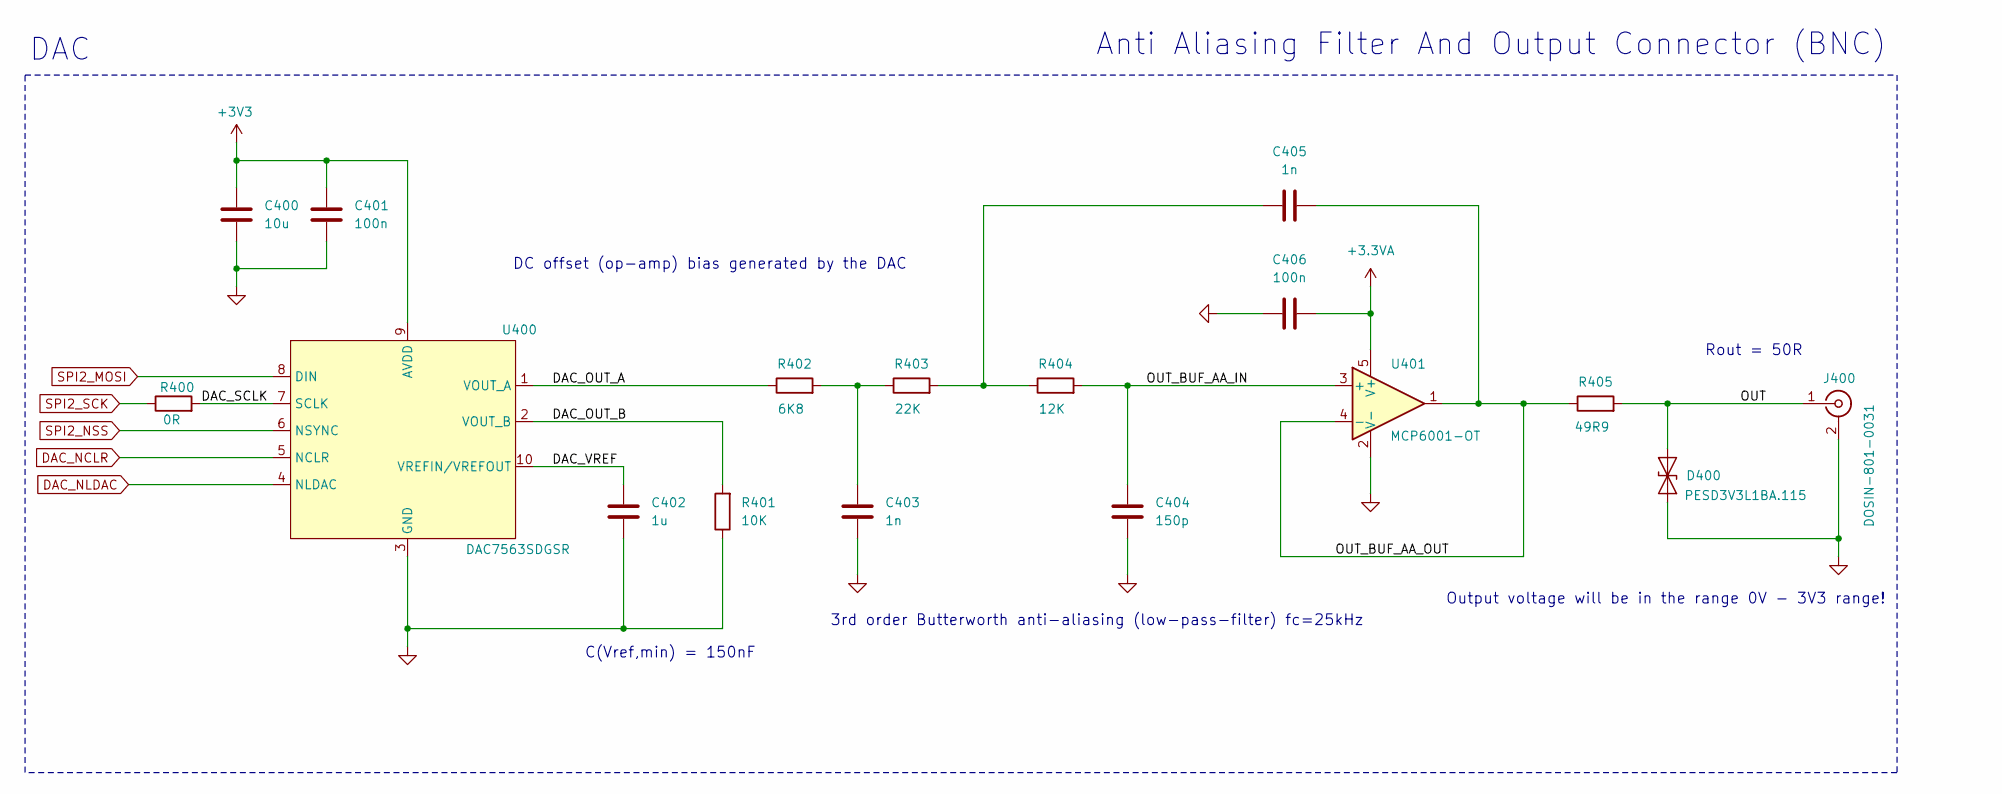
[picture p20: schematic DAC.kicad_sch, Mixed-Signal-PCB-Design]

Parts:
C400: 10u; C_0805_2012Metric; Manufacturer Part Number 0805X7R106KT1AT
C401, C406: 100n; C_0603_1608Metric; Manufacturer Part Number CC0603ZRY5V7BB104
C402: 1u; C_0805_2012Metric; Manufacturer Part Number 08055D105KAT2A
C403, C405: 1n; C_0603_1608Metric; Manufacturer Part Number VJ0603H102KEBAO34
C404: 150p; C_0603_1608Metric; Manufacturer Part Number VJ0603A151JXAAC
D400: PESD3V3L1BA.115; D_SOD-323; Manufacturer Part Number PESD3V3L1BA,115
J400: DOSIN-801-0031; BNC; Manufacturer Part Number DOSIN-801-003
R400: 0R; R_0603_1608Metric; Manufacturer Part Number RC0603JR-070RL
R401: 10K; R_0603_1608Metric; Manufacturer Part Number RC0603FR-0710KL
R402: 6K8; R_0603_1608Metric; Manufacturer Part Number RC0603FR-076K8L
R403: 22K; R_0603_1608Metric; Manufacturer Part Number RC0603FR-0722KL
R404: 12K; R_0603_1608Metric; Manufacturer Part Number RC0603FR-0712KL
R405: 49R9; R_0603_1608Metric; Manufacturer Part Number RC0603FR-0749R9L
U400: DAC7563SDGSR; SOIC-10; Manufacturer Part Number DAC7563SDGSR
U401: MCP6001-OT; SOT-23-5; Manufacturer Part Number MCP6001T‑I/OT

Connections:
+3.3VA: C406.2, U401.5 (V+); also elsewhere on the board
+3V3: C400.1, C401.1, U400.9 (AVDD); also elsewhere on the board
/DAC/DAC_OUT_A: R402.1, U400.1 (VOUT_A)
/DAC/DAC_OUT_B: R401.2, U400.2 (VOUT_B)
/DAC/DAC_SCLK: R400.2, U400.7 (SCLK)
/DAC/DAC_VREF: C402.1, U400.10 (VREFIN/VREFOUT)
/DAC/OUT: D400.2 (A2), J400.1 (In), R405.2
/DAC/OUT_BUF_AA_IN: C404.1, R404.2, U401.3 (+)
/DAC/OUT_BUF_AA_OUT: C405.2, R405.1, U401.1, U401.4 (-)
DAC_NCLR: U400.5 (NCLR); also elsewhere on the board
DAC_NLDAC: U400.4 (NLDAC); also elsewhere on the board
GND: C400.2, C401.2, C402.2, C403.2, C404.2, C406.1, D400.1 (A1), J400.2 (Ext), R401.1, U400.3 (GND), U401.2 (V-); also elsewhere on the board
unnamed: C403.1, R402.2, R403.1
unnamed: C405.1, R403.2, R404.1
SPI2_MOSI: U400.8 (DIN); also elsewhere on the board
SPI2_NSS: U400.6 (NSYNC); also elsewhere on the board
SPI2_SCK: R400.1; also elsewhere on the board

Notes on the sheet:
Output voltage will be in the range 0V - 3V3 range!
Anti Aliasing Filter And Output Connector (BNC)
C(Vref,min) = 150nF
3rd order Butterworth anti-aliasing (low-pass-filter) fc=25kHz
DAC
DC offset (op-amp) bias generated by the DAC
Rout = 50R

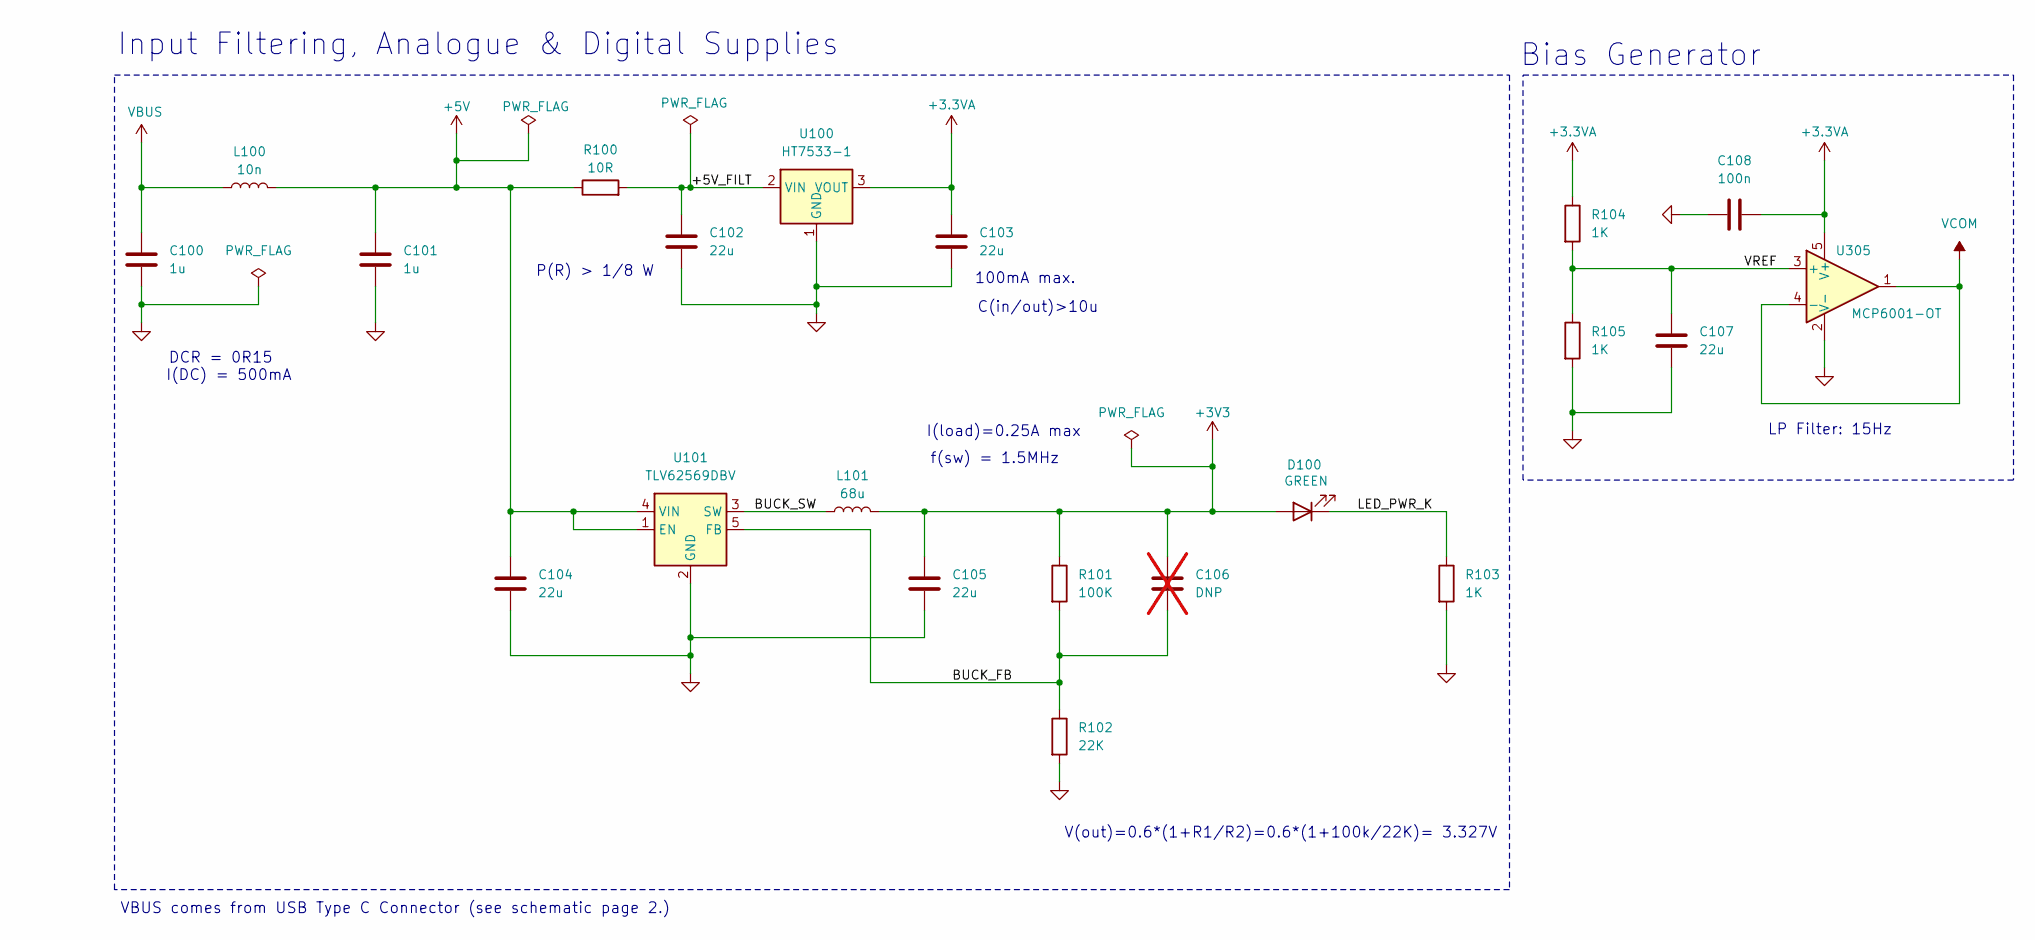
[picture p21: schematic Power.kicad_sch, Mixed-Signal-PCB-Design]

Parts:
C100, C101: 1u; C_0805_2012Metric; Manufacturer Part Number 08055D105KAT2A
C102, C103, C104, C105, C107: 22u; C_0805_2012Metric; Manufacturer Part Number 0805YD226MAT2A
C106: DNP; C_0805_2012Metric; not fitted
C108: 100n; C_0603_1608Metric; Manufacturer Part Number CC0603ZRY5V7BB104
D100: GREEN; D_0805_2012Metric; Manufacturer Part Number LTST-C170FKT
L100: 10n; L_0603_1608Metric; Manufacturer Part Number MWSA0603S-100J
L101: 68u; L_Sunlord_MWSA0603S; Manufacturer Part Number MWSA0603S-680K
R100: 10R; R_0603_1608Metric; Manufacturer Part Number RC0603FR-0710RL
R101: 100K; R_0603_1608Metric; Manufacturer Part Number RC0603FR-07100KL
R102: 22K; R_0603_1608Metric; Manufacturer Part Number RC0603FR-0722KL
R103, R104, R105: 1K; R_0603_1608Metric; Manufacturer Part Number RC0603FR-071KL
U100: HT7533-1; SOT-89-3; Manufacturer Part Number HT7533-1
U101: TLV62569DBV; SOT-23-5; Manufacturer Part Number TLV62569DBV
U305: MCP6001-OT; SOT-23-5; Manufacturer Part Number MCP6001-OT

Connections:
+3.3VA: C103.1, C108.2, R104.1, U100.3 (VOUT), U305.5 (V+); also elsewhere on the board
+3V3: C105.1, C106.1, D100.2 (A), L101.2, R101.1; also elsewhere on the board
+5V: C101.1, C104.1, L100.2, R100.1, U101.1 (EN), U101.4 (VIN); also elsewhere on the board
/Power/+5V_FILT: C102.1, R100.2, U100.2 (VIN)
/Power/BUCK_FB: C106.2, R101.2, R102.1, U101.5 (FB)
/Power/BUCK_SW: L101.1, U101.3 (SW)
/Power/LED_PWR_K: D100.1 (K), R103.1
/Power/VREF: C107.1, R104.2, R105.1, U305.3 (+)
GND: C100.2, C101.2, C102.2, C103.2, C104.2, C105.2, C107.2, C108.1, R102.2, R103.2, R105.2, U100.1 (GND), U101.2 (GND), U305.2 (V-); also elsewhere on the board
VBUS: C100.1, L100.1; also elsewhere on the board
VCOM: U305.1, U305.4 (-); also elsewhere on the board

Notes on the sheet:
DCR = 0R15 I(DC) = 500mA
V(out)=0.6*(1+R1/R2)=0.6*(1+100k/22K)= 3.327V
P(R) > 1/8 W
C(in/out)>10u
VBUS comes from USB Type C Connector (see schematic page 2.)
I(load)=0.25A max
100mA max.
Bias Generator
Input Filtering, Analogue & Digital Supplies
f(sw) = 1.5MHz
LP Filter: 15Hz

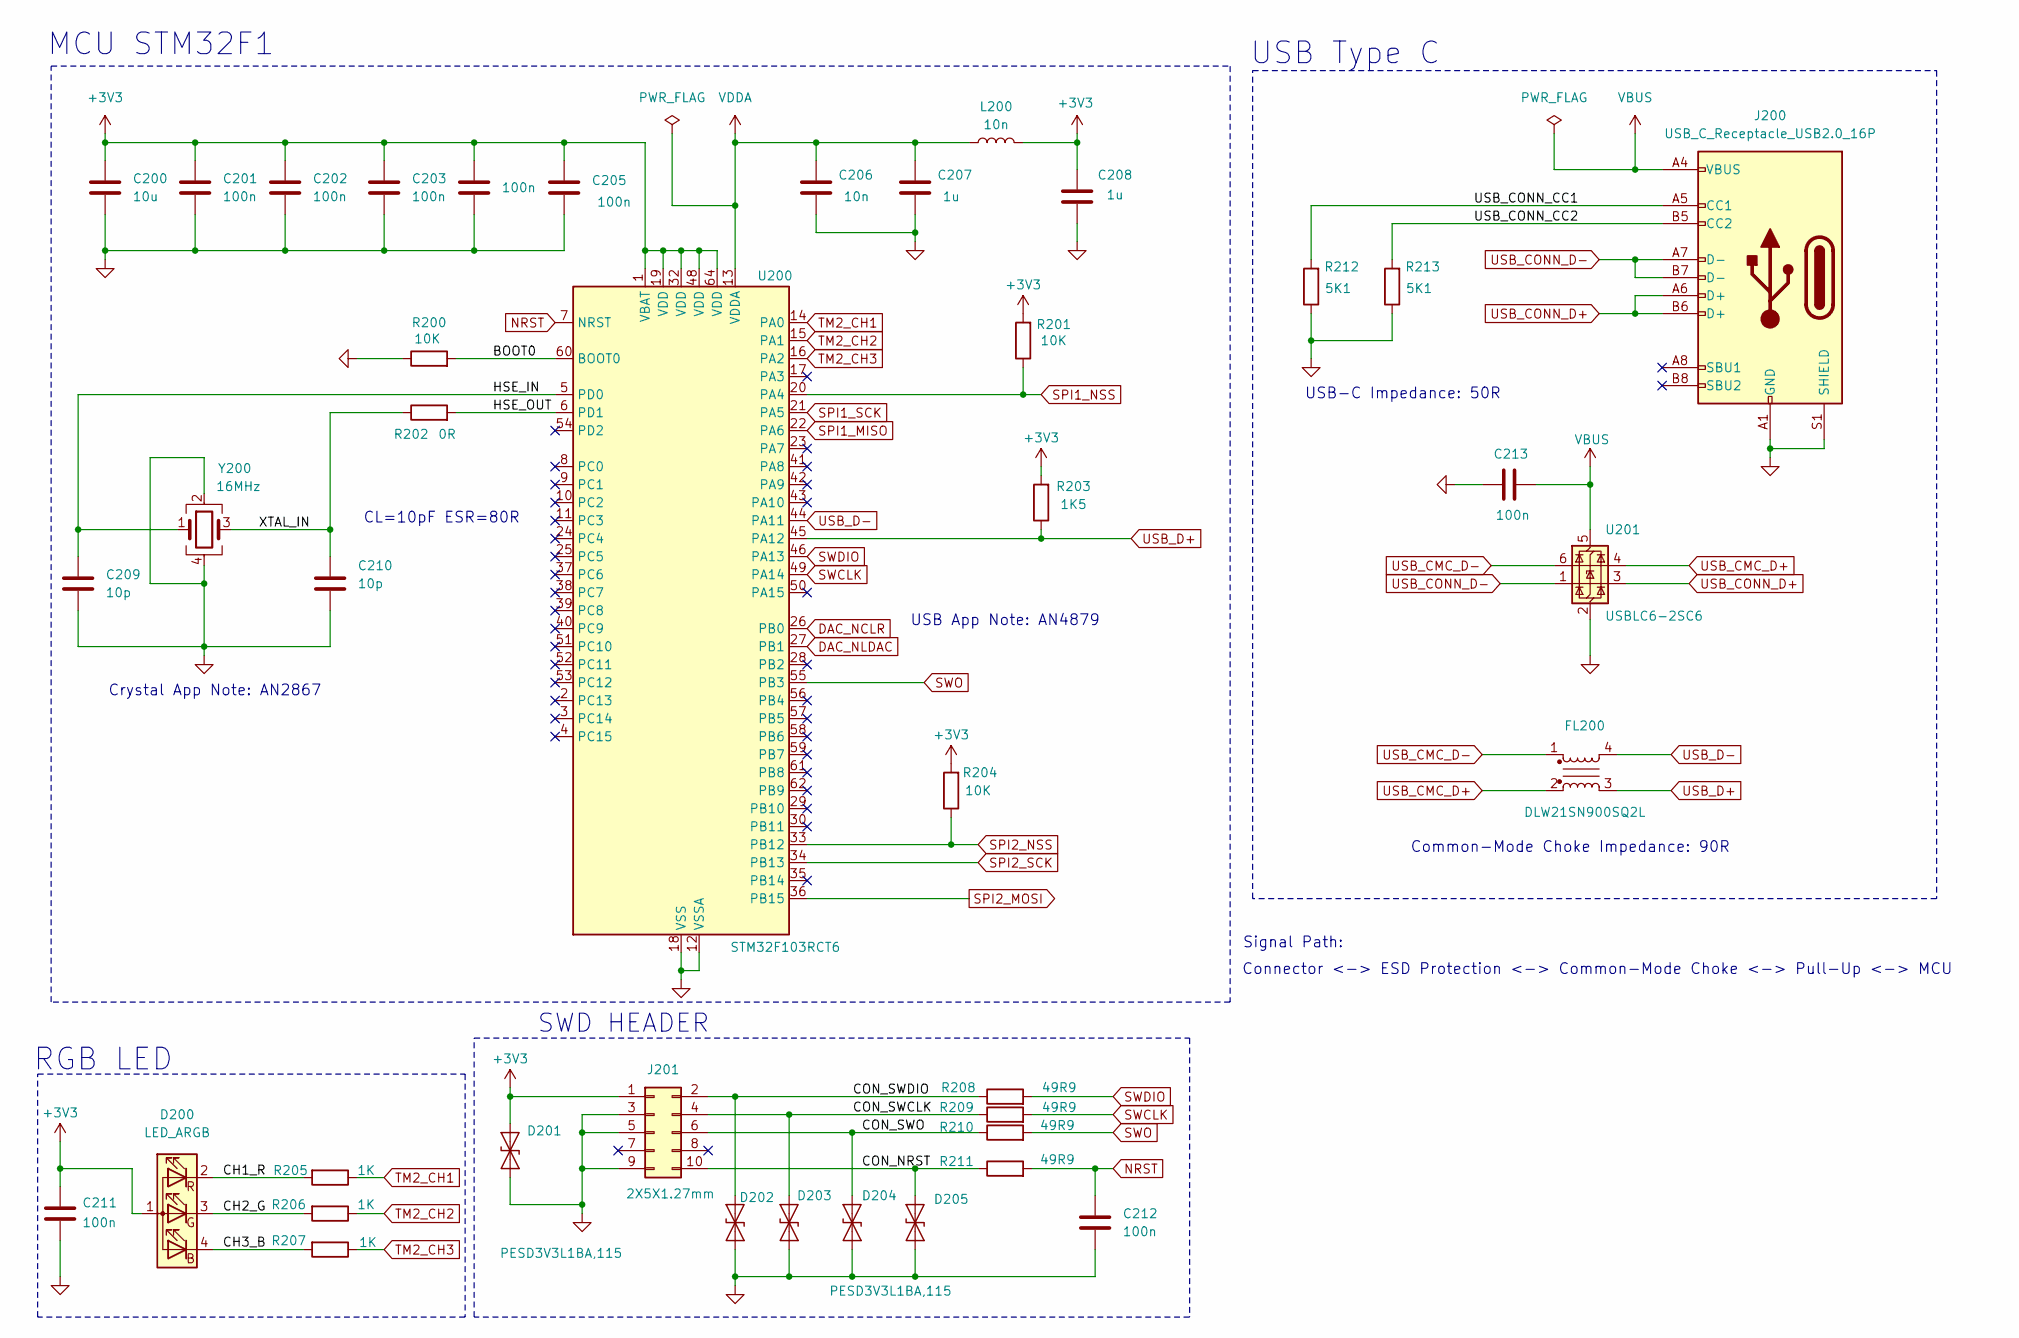
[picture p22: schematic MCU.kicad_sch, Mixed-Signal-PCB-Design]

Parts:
C200: 10u; C_0805_2012Metric; Manufacturer Part Number 0805X7R106KT1AT
C201, C202, C203, C204, C205, C211, C212, C213: 100n; C_0603_1608Metric; Manufacturer Part Number CC0603ZRY5V7BB104
C206: 10n; C_0603_1608Metric; Manufacturer Part Number VJ0603Y103KXJAC31X
C207, C208: 1u; C_0805_2012Metric; Manufacturer Part Number 08055D105KAT2A
C209, C210: 10p; C_0603_1608Metric; Manufacturer Part Number VJ0603A100FXBAC
D200: LED_ARGB; LED_AAA3528LSEEZGKQBKS_KNB; Manufacturer Part Number AAA3528LSEEZGKQBKS
D201, D202: PESD3V3L1BA,115; D_SOD-323; Manufacturer Part Number PESD3V3L1BA,115
D203, D204, D205: SD05_SOD323; D_SOD-323; Manufacturer Part Number PESD3V3L1BA,115
FL200: DLW21SN900SQ2L; choke; Manufacturer Part Number DLW21SN900SQ2L
J200: USB_C_Receptacle_USB2.0_16P; USB_C_Receptacle_HRO_TYPE-C-31-M-12; Manufacturer Part Number TYPE-C-31-M-12
J201: 2X5X1.27mm; PinHeader_2x05_P1.27mm_Vertical_SMD; Manufacturer Part Number FTSH-105-01-L-DV-K
L200: 10n; L_0603_1608Metric; Manufacturer Part Number LQW18AN10NJ00D
R200, R201, R204: 10K; R_0603_1608Metric; Manufacturer Part Number RC0603FR-0710KL
R202: 0R; R_0603_1608Metric; Manufacturer Part Number RC0603JR-070RL
R203: 1K5; R_0603_1608Metric; Manufacturer Part Number RC0603FR-071K5L
R205, R206, R207: 1K; R_0603_1608Metric; Manufacturer Part Number RC0603FR-071KL
R208, R209, R210, R211: 49R9; R_0603_1608Metric; Manufacturer Part Number RC0603FR-0749R9L
R212, R213: 5K1; R_0603_1608Metric; Manufacturer Part Number RC0603FR-075K1L
U200: STM32F103RCT6; LQFP-64_10x10mm_P0.5mm; Manufacturer Part Number STM32F103RCT6
U201: USBLC6-2SC6; SOT-23-6; Manufacturer Part Number USBLC6-2SC6
Y200: 16MHz; Crystal_SMD_3225-4Pin_3.2x2.5mm; Manufacturer Part Number FA-238 16.000 MHz

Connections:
+3V3: C200.1, C201.1, C202.1, C203.1, C204.1, C205.1, C208.1, C211.1, D200.1 (A), D201.2 (A2), J201.1, L200.2, R201.2, R203.2, R204.2, U200.1 (VBAT), U200.19 (VDD), U200.32 (VDD), U200.48 (VDD), U200.64 (VDD); also elsewhere on the board
/MCU/BOOT0: R200.2, U200.60 (BOOT0)
/MCU/CH1_R: D200.2 (RK), R205.2
/MCU/CH2_G: D200.3 (GK), R206.2
/MCU/CH3_B: D200.4 (BK), R207.2
/MCU/CON_NRST: D205.2 (A2), J201.10, R211.1
/MCU/CON_SWCLK: D203.2 (A2), J201.4, R209.1
/MCU/CON_SWDIO: D202.2 (A2), J201.2, R208.1
/MCU/CON_SWO: D204.2 (A2), J201.6, R210.1
/MCU/HSE_IN: C209.1, U200.5 (PD0), Y200.1
/MCU/HSE_OUT: R202.2, U200.6 (PD1)
/MCU/USB_CONN_CC1: J200.A5 (CC1), R212.2
/MCU/USB_CONN_CC2: J200.B5 (CC2), R213.2
/MCU/XTAL_IN: C210.1, R202.1, Y200.3
DAC_NCLR: U200.26 (PB0); also elsewhere on the board
DAC_NLDAC: U200.27 (PB1); also elsewhere on the board
GND: C200.2, C201.2, C202.2, C203.2, C204.2, C205.2, C206.2, C207.2, C208.2, C209.2, C210.2, C211.2, C212.2, C213.1, D201.1 (A1), D202.1 (A1), D203.1 (A1), D204.1 (A1), D205.1 (A1), J200.A1 (GND), J200.A12 (GND), J200.B1 (GND), J200.B12 (GND), J200.S1 (SHIELD), J201.3, J201.5, J201.9, R200.1, R212.1, R213.1, U200.12 (VSSA), U200.18 (VSS), U200.31 (VSS), U200.47 (VSS), U200.63 (VSS), U201.2 (GND), Y200.2, Y200.4; also elsewhere on the board
NRST: C212.1, R211.2, U200.7 (NRST)
SPI1_MISO: U200.22 (PA6); also elsewhere on the board
SPI1_NSS: R201.1, U200.20 (PA4); also elsewhere on the board
SPI1_SCK: U200.21 (PA5); also elsewhere on the board
SPI2_MOSI: U200.36 (PB15); also elsewhere on the board
SPI2_NSS: R204.1, U200.33 (PB12); also elsewhere on the board
SPI2_SCK: U200.34 (PB13); also elsewhere on the board
SWCLK: R209.2, U200.49 (PA14)
SWDIO: R208.2, U200.46 (PA13)
SWO: R210.2, U200.55 (PB3)
TM2_CH1: R205.1, U200.14 (PA0)
TM2_CH2: R206.1, U200.15 (PA1)
TM2_CH3: R207.1, U200.16 (PA2)
USB_CMC_D+: FL200.2, U201.4 (I/O1)
USB_CMC_D-: FL200.1, U201.6 (I/O1)
USB_CONN_D+: J200.A6 (D+), J200.B6 (D+), U201.3 (I/O2)
USB_CONN_D-: J200.A7 (D-), J200.B7 (D-), U201.1 (I/O2)
USB_D+: FL200.3, R203.1, U200.45 (PA12)
USB_D-: FL200.4, U200.44 (PA11)
VBUS: C213.2, J200.A4 (VBUS), J200.A9 (VBUS), J200.B4 (VBUS), J200.B9 (VBUS), U201.5 (VBUS); also elsewhere on the board
VDDA: C206.1, C207.1, L200.1, U200.13 (VDDA)

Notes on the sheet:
Crystal App Note: AN2867
CL=10pF ESR=80R
Connector <-> ESD Protection <-> Common-Mode Choke <-> Pull-Up <-> MCU
USB App Note: AN4879
RGB LED
Signal Path:
SWD HEADER
Common-Mode Choke Impedance: 90R
USB-C Impedance: 50R
USB Type C
MCU STM32F1

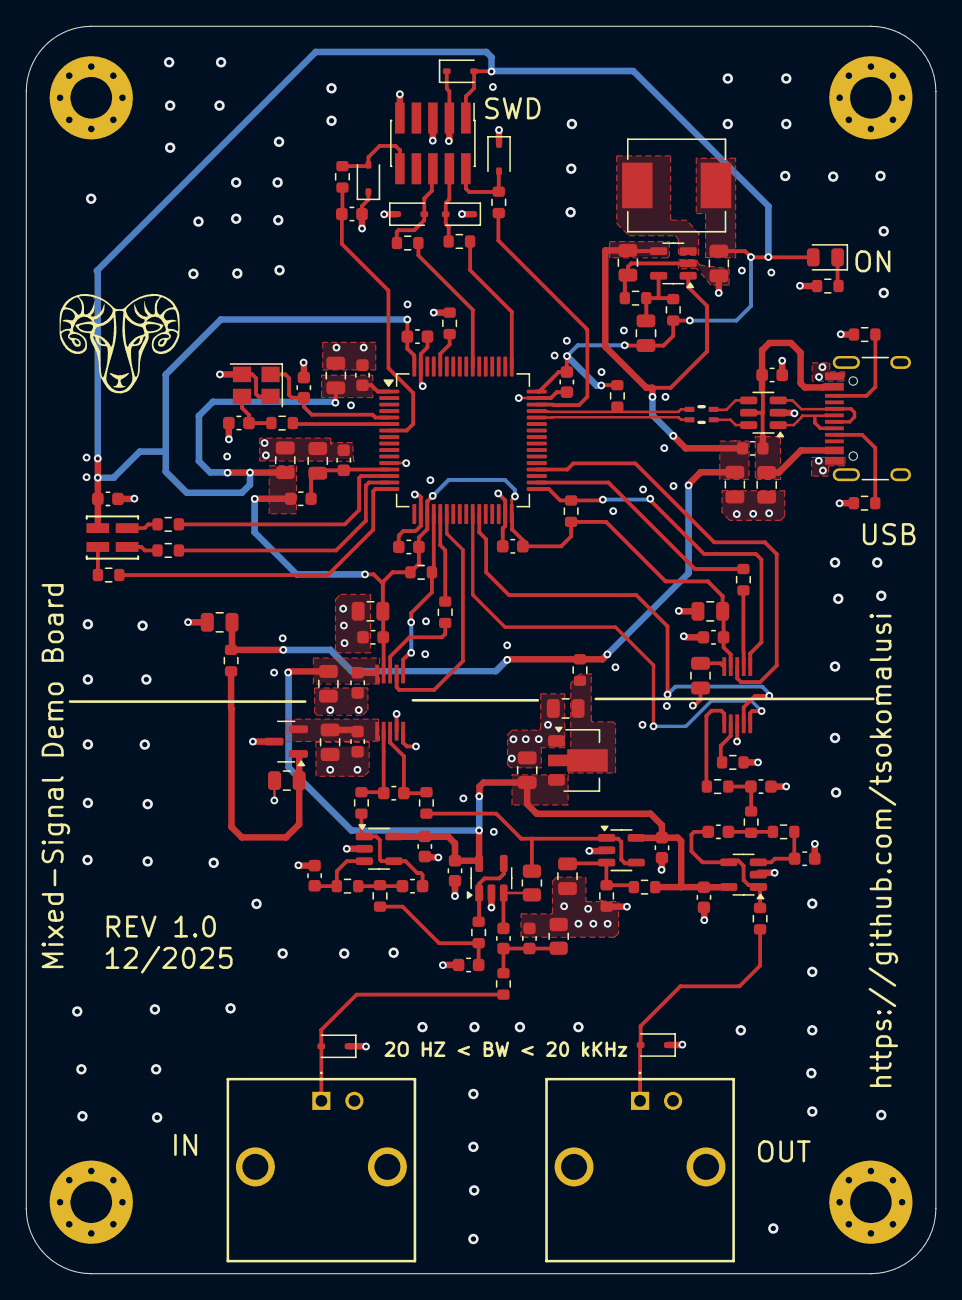
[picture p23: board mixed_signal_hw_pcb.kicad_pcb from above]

Board: 4 copper layers, 70.0 x 96.0 mm, 115 parts (0 on the bottom side), 68 nets.

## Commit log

2025-12-28 uploading design files
    [5222092-1.step, AAA3528LSEEZGKQBKS.step, ADC.kicad_sch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]
2025-12-28 schematic files upload
